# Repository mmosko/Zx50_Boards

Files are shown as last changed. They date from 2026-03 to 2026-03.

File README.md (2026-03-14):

# Zx50 Project Architecture Context

## Overview

The Zx50 is a custom 8-slot, passive backplane Z80 computer. It uses a "Shadow Bus" architecture where a Raspberry Pi Pico can take over the bus via DMA (~BUSRQ / ~BUSAK) to load RAM, debug, and monitor the system.

## Core Rules & Hardware

* Backplane: 8 slots. Fully terminated with 10K SIP pull-up resistors on Address, Data, and Control lines. Includes an ~IEI/~IEO interrupt daisy chain and heavy bulk capacitance (1000µF).

* CPU: Z80 running at 8 to 10 MHz.

* Clock System: A dedicated Clock Mezzanine board that generates a 40 MHz Master Clock (MCLK) for the Pi Picos, and uses a 74HC393 to divide it down to a 10 MHz ZCLK for the Z80. It uses an async-request latch system (1G79, 1G08, 1G32) to perfectly sync the CPU clock stopping/stepping with the Pi Pico's requests, ensuring no runt pulses.

* Logic Families: * 74AHCT (specifically 74AHCT244 and 74AHCT245) are used for bus transceivers to provide the strong ±8mA current needed to drive the backplane.

* Standard 74HC / 74AHC logic is used for local onboard glue logic.

* System Reset: Handled by an MCP1316M-46LE/OT Open-Drain Supervisor IC on the CPU card. It provides a ~200ms reset timeout to allow the backplane capacitors to charge and the Pi Pico bootloaders to initialize before the Z80 wakes up.

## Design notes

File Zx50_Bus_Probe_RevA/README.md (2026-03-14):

# Zx50 Bus Probe & Injector Card (Rev A)

## 1. Overview and Purpose
The Zx50 Bus Probe is a hybrid diagnostic tool designed specifically for a Z80-based Zx50 backplane architecture. It serves as an active oscilloscope probe, an arbitrary signal injector, and a digital logic analyzer tap. 

Instead of manually moving oscilloscope probes across an active backplane, the Zx50 Probe allows a user to digitally route any of the 72 backplane signals to a central BNC output, inject external signals via a BNC input, and monitor system health via an onboard UI.

There is a Receiver card that attaches to the Zx50 bus.  It has a Pi PICO as the interface to a host computer.  The Pico orchestrates the backplane signal multiplexing.  It is attached via SPI to an 18F4620 PIC that has two GPIO expanders.  The PIC is the Zx50 bus debugger.  It can read or write to the bus and it can control the clocks.  The 18F4620 uses its onboard SPI to talk to the GPIO expanders and the UART to talk to the Pico.  A to-be-determined serial protocol allows the Pico to send commands or read data from the 4620.  The intent is the 4620 has a simple command monitor and rarely needs flash updates.  The Pico has complex software in Python that is easier to program and update.

There is a Sender card that attaches to the Receiver via 2x5 ribbon cable.  The Sender card attaches to an AFG to put signals on backplane traces.  These can be monitored by the Receiver.  Both sender and receiver have high-speed op amps and BNC connectors to attach to lab equipment.

## 2. The Universal Board Architecture
To minimize fabrication costs and guarantee matched signal paths, the system is designed as a **Universal PCB**. A single board design can be populated differently to serve as either the "Receiver" (The Brain) or the "Sender" (The Drone).

* **The Receiver (Master):** Populated with a Raspberry Pi Pico (RP2040) and a PIC18F4620. It orchestrates the signal routing, generates hardware-level system clocks, handles high-speed Z80 interrupts (`~WAIT~`, `~INT~`), and hosts the physical User Interface.
* **The Sender (Slave):** The Pi Pico and PIC are left unpopulated. It relies on the Receiver to command its local analog matrix via a 10-pin right-angle IDC ribbon cable.
* **The Jumper Matrix (3x7 Block):** A physical 21-pin routing block determines the board's role by directing the 5V control signals:
  * **Position 1-2 (Receiver Mode):** The onboard Pico drives both the local analog matrix and the remote Sender board via the ribbon cable.
  * **Position 2-3 (Sender Mode / Mirror Mode):** The local analog matrix is driven by external signals arriving from the ribbon cable.

## 3. Core Subsystems

### A. The "Voltage Firewall" (Level Shifting)
The Pi Pico operates strictly at 3.3V, while the Zx50 backplane and logic operate at 5.0V. 
* A **`74AHCT541`** buffer acts as a unidirectional level shifter and line driver.
* The "T" (TTL-compatible) inputs interpret the Pico's 3.3V signals as a valid logic HIGH, stepping them up to a robust 5.0V to drive the local multiplexers and safely push signals down the ribbon cable to the Sender board.

### B. The Analog Matrix
The core of the probing capability is a massive 72-channel crosspoint matrix.
* **Multiplexers:** Nine `CD74HC4051E` 8-channel analog multiplexers (High-Speed CMOS variant chosen over legacy `CD4051BE` to ensure <70Ω $R_{ON}$ and >100MHz bandwidth for sharp Z80 square waves).
* **Decoding:** A 4-to-16 line decoder (`74HC154` or cascaded `74HC138`s) manages the Chip Select lines for the multiplexers. Sending address `1111` (15) targets a "Phantom Mux," safely disabling the entire matrix to isolate the test equipment from the bus.
* **Op-Amps:** High-speed `OPA356xxD` CMOS operational amplifiers buffer the analog signals immediately before the `IN` and `OUT` BNC jacks to prevent the oscilloscope or function generator from loading the backplane.

### C. The Dedicated Logic Analyzer Field
To support professional diagnostic equipment (e.g., Tektronix logic analyzers), the rear of the card features a raw, unbuffered test point field.
* Arranged in standard 2xN 2.54mm pitch groupings spaced out by function: `ADDR [0:15]`, `DATA [0:7]`, `CTRL [0:7]`, `SHADOW_DATA [0:7]`, `SHADOW_CTRL [0:7]`, and `CLOCK [0:1]`.
* **Dedicated Ground Row:** Every signal pin is paired directly with an adjacent `GND` pin (Row 2), ensuring short return paths and pristine signal integrity for flying-lead probes.
* The headers are intentionally unbuffered, relying on the <2pF capacitance of professional logic analyzer pods to spy on the true analog state of the bus.

## 4. Mechanical & Physical Design

* **Asymmetric "Tower" Form Factor:** The PCB utilizes an inverted-T (or L-shaped) `Edge.Cuts` profile. The base fits the standard 5-inch Zx50 card dimensions, while the front UI section extends upward to 7 inches. This ensures the display and status LEDs clear the adjacent memory/CPU cards in the chassis.
* **User Interface:**
  * **Primary Display:** An `EA DIP205-4` 20x4 Character LCD, mounted flush to the PCB. It runs natively on the Pico's 3.3V SPI bus, with a dedicated 33Ω resistor dropping the 5V rail for the yellow/green backlight.
  * **Status LEDs:** Three right-angle horizontal LEDs (`CLK`, `MCLK`, `PWR`) mounted on the top edge of the board to provide immediate, bench-visible heartbeat and clock status.
* **Horizontal Interconnects:** The PIC ICSP programming header (`J4`) and the Sender/Receiver ribbon cable header (`J8`) use right-angle footprints to prevent cable collisions with adjacent Zx50 cards.

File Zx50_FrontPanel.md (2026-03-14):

# Zx50 Front Panel Card

This card drives the flashy front panel.  The front panel will have LEDs for bus state
plus a programmable LCD display (e.g. EA DIP205G-4NLED SPI).  It will also have
some system control switches.

## Physical Interface

- LCD Display: Driven by a Pi PICO on the front panel card, it can display messages
from the Pico or the Z80.

- LEDs
  - Z80 Address [0:15]
  - Z80 Data [0:8]
  - Z80 Control (about 12 of them)
  - Shadow Bus data [0:8]
  - Shadow Bus control (8 lines)
  - Power
  - Some of these could be hex digit mult-segment

- Switches
  - Power switch (e.g. SPST to turn on power supply)
  - Run/Stop (SPST pulls line low)
  - Step (momentary, pulls line low)

## Pico Interface

The Pico controls multple tri-state buffers (e.g. '244) attached to the different
8-bit buses (address hi, address low, data, control, shadow data, shadow control).
It reads each bus periodically and updates the front panel LEDs.

There is an IORQ decoder chip that fires an interrupt whenever the Z80 writes to
the front panel card's IO address.  The Z80 can transfer commands to the Pico
by using, e.g. OTIR transfers.  During an I/O instruction, the Z80 places the contents of the B register on the upper address bus (A8-A15), while the C register (the port address) goes on the lower bus (A0-A7).

Because OTIR decrements B with every loop, the Pico literally gets a real-time hardware countdown timer handed to it on A8-A15 with every single byte.  At the end of the burst,
the Pico can udpate the LCD display from its local memory.

Because the Pico has fast PIO (Programmable I/O) state machines, it does not even need to write this in C. You can write a tiny 4-line PIO assembly program that just sits there, watching the ~IORQ pin, and instantly pushes those 16 pins into a DMA FIFO buffer for your main Pico code to read at its leisure. It won't miss a single byte, even at 8MHz, 10MHz, or 20MHz.

## Shadow Bus transfers

The other option is for the Pico to work as a Shadow Bus slave or master.  The Z80 can setup a
DMA transfer from meory to the Pico, and this can then run at 40 MHz.

See [Zx50 Bus Protocol](https://github.com/mmosko/Zx50Bus/blob/main/README.md).

## Physical UI and the Zx50 CPU Card

The Front Panel card attaches via two 2x50 cables to the front panel.  One is for the
SPI control of the LCD display.  The other is for updating the LCDs and the physical
switches.  A small MCU (e.g. small 18Fxxxx) controls the LEDs based on commands from
the Pico.

This arrangement allows one to use the fancy front panel control card or bypass it
directly to the CPU card for a minimum interface.

Front Panel Connector (exact pinout TBD, 2x5 IDC)
1. +5V
2. +5V
3. TX (from Pico level shifter)
4. RX (to Pico level shifter)
5. TBD
6. Power switch
7. Reset switch
8. Step switch
9. GND
10. GND

Note that the Zx50 CPU card has the exact same header on it, so one could attach

LCD Display Connector (2x5 IDC)
- 3.3V
- SCLK
- SDI (to Pico)
- SDO (from pico)
- GND
- RST (~MCLR)

## Interface to Zx50 Bus Probe

It is desirable for the Zx50 Bus Probe to see the Step switch.  The Reset switch is
already on the bus.  The Step switch will use Pin 80 (labelled AUX).  Both the
Zx80 CPU card and the Front Panel card will tie the Front Panel connector 
Step switch (after debouncing) to pin 80.  The Zx50 bus already has a pull up on AUX, so
the switches only need to pull low.

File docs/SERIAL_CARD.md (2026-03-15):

# Zx50 Serial I/O & Timer Card (CTC + DART)

## 1. Overview
This card provides the Zx50 system with its primary human-machine interface (via two serial ports) and precision hardware timing. It combines a **Z80 DART** (Dual Asynchronous Receiver/Transmitter) for serial communications and a **Z80 CTC** (Counter/Timer Circuit) for programmable baud rate generation and system tick interrupts.

## 2. Core Chip Manifest
1. **Z80 DART (Z84C40):** The dual serial controller.
2. **Z80 CTC (Z84C30):** The 4-channel timer (provides baud rate clocks to the DART and system ticks).
3. **74AHCT245:** Octal bus transceiver (Firewall for the `D0-D7` data bus).
4. **74AHCT138:** 3-to-8 line decoder (Address slicing for the Z80 I/O space).
5. **MAX232 (or MAX3232):** RS-232 level shifter charge-pump (Dedicated to Serial Port 1).
6. **7.3728 MHz Oscillator:** A standard 4-pin active crystal oscillator can (feeds the CTC's clock inputs).
7. **FTDI DB9-USB-D5:** Standalone USB-to-TTL module (Physical connector and level translator for Serial Port 0).
8. *(Optional Glue Logic):* `74AHCT32` or `74AHCT04` to qualify `~IORQ` and `~M1` for the address decoder.

## 3. The Output Stages (The Split Design)
* **Serial 0 (USB via FTDI):**
  * **Source:** Z80 DART Channel A.
  * **Connector:** FTDI DB9-USB-D5 module.
  * **Voltages:** 5V TTL logic. The DART's `TXA`, `RXA`, `~RTSA~`, and `~CTSA~` pins connect *directly* to the module's footprint.
* **Serial 1 (Classic RS-232):**
  * **Source:** Z80 DART Channel B.
  * **Connector:** Standard Right-Angle DB9 Female (PCB Mount).
  * **Voltages:** True RS-232 (±10V). The DART's `TXB`, `RXB`, `~RTSB~`, and `~CTSB~` pins route through the `MAX232` level-shifting IC before hitting the DB9.

## 4. Hardware Activity LEDs
To provide immediate visual feedback during data transmission, the board features hardware-driven activity LEDs:
* **Implementation:** High-efficiency LEDs are connected directly to the `TXA` and `TXB` output pins of the DART, pulled to ground through a 1KΩ or 2.2KΩ current-limiting resistor.
* **Result:** The LEDs will naturally flicker exactly when bytes are being shifted out of the UART, requiring zero software overhead or modem control line initialization.

## 5. The Baud Rate Engine (The CTC Hack)
Instead of using a dedicated baud rate generator chip, this board uses the classic Zilog design pattern: **Using the CTC to drive the DART.**
* **The Clock:** The `7.3728 MHz` crystal oscillator feeds the CTC's clock inputs (`CLK/TRG0` and `CLK/TRG1`). This specific frequency divides down perfectly into standard baud rates (115200, 9600, etc.).
* **The Routing:** * CTC Channel 0 Output (`ZC/TO0`) $\rightarrow$ DART Channel A `RxCA` / `TxCA` pins.
  * CTC Channel 1 Output (`ZC/TO1`) $\rightarrow$ DART Channel B `RxCB` / `TxCB` pins.
* **Result:** The Z80 can dynamically change the baud rate of either serial port on the fly by writing a new divisor to the respective CTC channel.

## 6. Interrupt Priority & The Daisy Chain
Both the CTC and the DART utilize **Z80 Mode 2 Vectored Interrupts**. Because they sit on the same physical card, their interrupt priority is hardwired using the Zx50 Backplane's `IEI` and `IEO` lines.
* **Routing Path:** `Backplane IEI` $\rightarrow$ `CTC IEI` | `CTC IEO` $\rightarrow$ `DART IEI` | `DART IEO` $\rightarrow$ `Backplane IEO`.
* **Priority:** The CTC has a higher interrupt priority than the DART. 

## 7. Addressing Configuration
Both chips map exclusively to the Z80 **I/O Space**.
* **DART:** Requires 4 contiguous ports (driven by `C/~D` and `B/~A` pins).
* **CTC:** Requires 4 contiguous ports (driven by `CS0` and `CS1` pins).
* **Decoder (74AHCT138):** Slices the lower 8 bits of the address bus. Assuming a base address of `0x80`:
  * `0x80 - 0x83`: Mapped to the CTC `~CE`.
  * `0x84 - 0x87`: Mapped to the DART `~CE`.

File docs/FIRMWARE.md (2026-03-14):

# Zx50 Bus Probe: Firmware Development Plan

## Phase 1: PIC18F4620 "Ghost Mode"
**Goal:** Guarantee the PIC processor boots up completely transparent to the Zx50 backplane to prevent electrical contention.
* **Toolchain:** Microchip MPLAB X & XC8 Compiler.
* **Process:** 1. Write a minimal `main.c` that initializes the system clock.
  2. Write `0xFF` to `TRISA`, `TRISB`, `TRISC`, `TRISD`, and `TRISE`. This explicitly sets every single GPIO pin to a High-Impedance (Input) state.
  3. Disable analog multiplexing on digital pins (`ADCON1 = 0x0F` or equivalent for the 4620).
  4. Enter a `while(1) { Sleep(); }` loop. 
* **Outcome:** The PIC is effectively removed from the circuit, safely clearing the runway for the Pi Pico.

## Phase 2: Automated Backplane Characterization
**Goal:** Use the Pi Pico to inject high-speed signals into the naked backplane while a PC orchestrates measurements via the Tektronix MDO3034.
* **Toolchain:** C/C++ SDK (Pico), Python + `pyvisa` (PC).
* **Process:**
  1. **Pico Firmware:** Write a simple USB-Serial command parser that listens for commands like `FREQ 10000000`. Use the Pico's PIO (Programmable I/O) to generate a mathematically perfect square wave on a designated Shadow Bus pin at the requested frequency.
  2. **Python Orchestrator:** Write a script on the PC that:
     * Connects to the Pico (COM port) and the Tektronix (Ethernet/IP).
     * Commands the Pico to start generating a 1MHz clock.
     * Commands the Tektronix to Auto-Scale, measure Peak-to-Peak voltage on the active line, and measure crosstalk (Vpp) on an adjacent quiet line.
     * Steps the frequency up to 40MHz in 1MHz increments, logging the data to a CSV.
* **Outcome:** A comprehensive bandwidth and crosstalk profile of the physical OSH Park backplane.

## Phase 3: Inter-Processor Communication (IPC)
**Goal:** Establish a reliable command-and-control protocol between the PIC and the Pico.
* **Architecture:** The Pico acts as the "High-Speed Brawn" (DMA, 40MHz signaling), while the PIC acts as the "Supervisor Brain" (handling the analog muxes `U2`-`U12` and steady-state Z80 monitoring).
* **Physical Layer:** Utilize the dedicated UART (`TX`/`RX`) or SPI pins running between the two chips on the Bus Probe board. 
* **Protocol:** Implement a simple packetized serial protocol (e.g., `[SYNC] [LENGTH] [COMMAND] [PAYLOAD] [CHECKSUM]`). 
  * Example Command: Pico tells PIC, *"Set Mux Array to route Z80 Address Line A15 to Analog Channel 1."*

## Phase 4: Full Bus Master & Monitor
**Goal:** Develop the software to freeze the Z80, take over the bus, and inject/read data.
* **Process:** 1. Pico asserts `~BUSRQ` and waits for `~BUSAK` from the Z80.
  2. Pico asserts `~OE` on the Bus Probe's transceiver firewall to physically connect itself to the backplane.
  3. Pico executes DMA transfers to memory or I/O, utilizing the PIC to monitor analog signal integrity during the transfer.

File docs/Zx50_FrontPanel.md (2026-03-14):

# Zx50 Front Panel Card

This card drives the flashy front panel.  The front panel will have LEDs for bus state
plus a programmable LCD display (e.g. EA DIP205G-4NLED SPI).  It will also have
some system control switches.

## Physical Interface

- LCD Display: Driven by a Pi PICO on the front panel card, it can display messages
from the Pico or the Z80.

- LEDs
  - Z80 Address [0:15]
  - Z80 Data [0:8]
  - Z80 Control (about 12 of them)
  - Shadow Bus data [0:8]
  - Shadow Bus control (8 lines)
  - Power
  - Some of these could be hex digit mult-segment

- Switches
  - Power switch (e.g. SPST to turn on power supply)
  - Run/Stop (SPST pulls line low)
  - Step (momentary, pulls line low)

## Pico Interface

The Pico controls multple tri-state buffers (e.g. '244) attached to the different
8-bit buses (address hi, address low, data, control, shadow data, shadow control).
It reads each bus periodically and updates the front panel LEDs.

There is an IORQ decoder chip that fires an interrupt whenever the Z80 writes to
the front panel card's IO address.  The Z80 can transfer commands to the Pico
by using, e.g. OTIR transfers.  During an I/O instruction, the Z80 places the contents of the B register on the upper address bus (A8-A15), while the C register (the port address) goes on the lower bus (A0-A7).

Because OTIR decrements B with every loop, the Pico literally gets a real-time hardware countdown timer handed to it on A8-A15 with every single byte.  At the end of the burst,
the Pico can udpate the LCD display from its local memory.

Because the Pico has fast PIO (Programmable I/O) state machines, it does not even need to write this in C. You can write a tiny 4-line PIO assembly program that just sits there, watching the ~IORQ pin, and instantly pushes those 16 pins into a DMA FIFO buffer for your main Pico code to read at its leisure. It won't miss a single byte, even at 8MHz, 10MHz, or 20MHz.

## Shadow Bus transfers

The other option is for the Pico to work as a Shadow Bus slave or master.  The Z80 can setup a
DMA transfer from meory to the Pico, and this can then run at 40 MHz.

See [Zx50 Bus Protocol](https://github.com/mmosko/Zx50Bus/blob/main/README.md).

## Physical UI and the Zx50 CPU Card

The Front Panel card attaches via two 2x50 cables to the front panel.  One is for the
SPI control of the LCD display.  The other is for updating the LCDs and the physical
switches.  A small MCU (e.g. small 18Fxxxx) controls the LEDs based on commands from
the Pico.

This arrangement allows one to use the fancy front panel control card or bypass it
directly to the CPU card for a minimum interface.

Front Panel Connector (exact pinout TBD, 2x5 IDC)
1. +5V
2. +5V
3. TX (from Pico level shifter)
4. RX (to Pico level shifter)
5. Power switch
6. Run switch
7. Reset switch
8. Step_N switch
9. GND
10. GND

Note that the Zx50 CPU card has the exact same header on it, so one could attach

LCD Display Connector (2x5 IDC)
- 3.3V
- SCLK
- SDI (to Pico)
- SDO (from pico)
- GND
- RST (~MCLR)

Wiring
- If only the CPU card is installed, the front panel Connetor is wired directly to
the CPU card.
- If the Front Panel Card is installed, the front panel connector goes to the Front panel
card, and then a daisy chain short ribbon cables goes from the front pane card to the cpu card,
to wire the RUN and STEP switches to the clock mezzanine. The CPU card does not use the AUX pin.
- There will be some 2 position jumpers on the CPU card to connect pin 79 to RUN and pin 80
to STEP_N, in case I want to do that.  Otherwise, it will leave the 16-bit GPIO pins free.

## Interface to Zx50 Bus Probe

It is desirable for the Zx50 Bus Probe to see the Step switch.  The Reset switch is
already on the bus.  The Step switch will use Pin 80 (labelled AUX). 

It is assumed that if one is using the bus probe to control the system, there is a control
PC somewhere with the main interface and the STEP switch is just a convencience.

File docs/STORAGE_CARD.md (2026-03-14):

# Zx50 NetStorage Card (Combo Ethernet & USB/SD)

## 1. Overview
The Zx50 NetStorage card provides the system with physical network connectivity and FAT16/FAT32 mass storage. By utilizing dual 8-bit parallel interfaces, both subsystems can achieve high-speed data transfers (and native Pi Pico DMA compatibility over the Shadow Bus) without bottlenecking the Z80.

## 2. Core Components
* **Ethernet:** **WIZnet W5300**. A high-performance hardware TCP/IP stack with a native 8-bit/16-bit parallel bus. (Configured in 8-bit mode). It features 8 independent hardware sockets and 128KB of internal TX/RX buffer memory.
* **Mass Storage:** **WCH CH376S**. A file management control chip that natively handles FAT file systems on USB flash drives and SD cards via an 8-bit parallel interface.
* **Bus Firewall:** Two `74AHCT245` transceivers for the Data bus, strictly controlled by the board's address decoder to prevent bus contention.

## 3. Addressing Strategy: Memory vs. I/O
The Z80 has two distinct addressing spaces: a 64KB Memory space and a 256-port (typically) I/O space. 

### Mass Storage (CH376S) -> I/O Mapped
* **Requirement:** The CH376S only requires **two** addresses: a Data port and a Command port.
* **Implementation:** We will map this to the standard Z80 I/O space using a `74AHCT138` decoder. For example, mapping it to I/O Ports `0x40` (Data) and `0x41` (Command). This uses almost zero real estate in the I/O map and is perfect for standard `IN A, (n)` and `OUT (n), A` instructions.

### Ethernet (W5300) -> Memory Mapped
* **Requirement:** The W5300 has a massive register set requiring **10 address lines** (`A0` through `A9`), effectively taking up 1024 bytes of address space. 
* **Implementation:** While the Z80 *can* do 16-bit I/O addressing via `IN A, (C)`, trying to cram 1KB of registers into the I/O space is messy. Instead, we will **Memory Map** the W5300. We will dedicate a 2KB or 4KB "window" in the Z80's upper memory space (e.g., `0xE000` to `0xE3FF`). 
* **Advantage:** Memory mapping allows the Z80 to use high-speed block move instructions (`LDIR`, `LDDR`) to blast data into the Ethernet transmit buffers exponentially faster than iterating through I/O ports.

## 4. Interrupts
Both chips feature active-low hardware interrupt pins (`~INT`). These will be tied into the Zx50 Backplane's open-drain `~INT` line, allowing either the Ethernet chip (e.g., "Packet Received") or the Storage chip (e.g., "File Read Complete") to flag the Z80 asynchronously.

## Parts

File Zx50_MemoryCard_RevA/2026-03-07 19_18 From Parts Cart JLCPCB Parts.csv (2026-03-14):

Parts Type | JLCPCB Part # | MFR Part # | Description | Unit Price | Qty | Total Price
stock | C14663 | CC0603KRX7R9BB104 | 100nF 50V X7R ±10% 0603 Multilayer Ceramic Capacitors MLCC - SMD/SMT ROHS | 0.0026 | 24 | 0.07
stock | C2062861 | IS61C256AL-12JLI-TR | -40℃~+85℃ 12ns 256Kbit 4.5V~5.5V 40mA 450uA Parallel Port (Parallel) SOJ-28 SRAM ROHS | 1.7867 | 1 | 1.79
stock | C3018881 | CY7C1049DV33-10ZSXIT | -40℃~+85℃ 10mA 10ns 3V~3.6V 4Mbit 90mA TSOPII-44-10.2mm SRAM ROHS | 9.0217 | 2 | 18.05
stock | C131956 | SN74ABT541BPWR | -40℃~+85℃ 1 250uA 2ns@5V,50pF 32mA 4.5V~5.5V 64mA 74ABT 8 Tri-State TSSOP-20 Buffers, Drivers, Receivers, Transceivers ROHS | 1.0957 | 2 | 2.2
stock | C1548132 | SN74ABT245BDW | -40℃~+85℃ 250uA 2ns@5V,50pF 32mA 4.5V~5.5V 64mA 74ABT Bidirectional Tri-State SOIC-20-300mil Buffers, Drivers, Receivers, Transceivers ROHS | 0.8491 | 3 | 2.55
stock | C2676105 | SN74ABT16244ADGGR | -40℃~+85℃ 32mA 3mA 4 4 4.5V~5.5V 64mA 74ABT Tri-State TSSOP-48-6.1mm Buffers, Drivers, Receivers, Transceivers ROHS | 1.3661 | 1 | 1.37
stock | C31179 | ATF1508AS-10AU100 | TQFP-100(14x14) Programmable Logic Device (CPLDs/FPGAs) ROHS | 20.8308 | 1 | 20.84

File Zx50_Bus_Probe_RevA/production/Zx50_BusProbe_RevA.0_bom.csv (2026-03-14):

Designator | Footprint | Quantity | Value | LCSC Part #
A1 | RaspberryPi_Pico_Common_Unspecified | 1 | RaspberryPi_Pico
C1, C10, C11, C12, C13, C14, C15, C16, C17, C18, C19, C2, C20, C3, C4, C5, C6, C7, C8, C9 | C_Disc_D5.0mm_W2.5mm_P2.50mm | 20 | .1uF
C21 | CP_Radial_Tantal_D5.0mm_P2.50mm | 1 | 10uF
D1 | LED_D5.0mm_Horizontal_O1.27mm_Z3.0mm | 1 | MCLK
D2 | LED_D5.0mm_Horizontal_O1.27mm_Z3.0mm | 1 | CLK
D3 | LED_D5.0mm_Horizontal_O1.27mm_Z3.0mm | 1 | PWR
J1 | PinSocket_2x40_P2.54mm_Horizontal_Edge | 1 | Zx50_EdgeConnector
J10 | PinHeader_1x03_P2.54mm_Vertical | 1 | CH1
J11 | PinHeader_1x03_P2.54mm_Vertical | 1 | CH2
J12 | PinHeader_1x03_P2.54mm_Vertical | 1 | CH3
J15 | PinHeader_2x16_P2.54mm_Vertical_Row_Letter_Last | 1 | Z80_Addr
J16 | PinHeader_2x08_P2.54mm_Vertical_Row_Letter_Last | 1 | Z80_Data
J17 | PinHeader_2x08_P2.54mm_Vertical_Row_Letter_Last | 1 | Z80_Ctrl
J18 | PinHeader_2x02_P2.54mm_Vertical_Row_Letter_Last | 1 | Clock
J19 | PinHeader_2x08_P2.54mm_Vertical_Row_Letter_Last | 1 | SH_Data
J2 | BNC_Amphenol_B6252HB-NPP3G-50_Horizontal | 1 | OUT
J20 | PinHeader_2x08_P2.54mm_Vertical_Row_Letter_Last | 1 | SH_Ctrl
J3 | BNC_Amphenol_B6252HB-NPP3G-50_Horizontal | 1 | IN
J4 | PinHeader_1x06_P2.54mm_Horizontal_EDGE | 1 | PIC PGM
J5 | PinHeader_1x03_P2.54mm_Vertical | 1 | P0
J6 | PinHeader_1x03_P2.54mm_Vertical | 1 | P1
J7 | PinHeader_1x03_P2.54mm_Vertical | 1 | P2
J8 | IDC-Header_2x05_P2.54mm_Horizontal_Edge | 1 | Send/Recv Card
J9 | PinHeader_1x03_P2.54mm_Vertical | 1 | CH0
LCD1 | EA_DIG205G-4NLED | 1 | EA 205G-4NLED
R1, R2 | R_Axial_DIN0207_L6.3mm_D2.5mm_P10.16mm_Horizontal | 2 | 49.9R 1W 1%
R10 | R_Axial_DIN0207_L6.3mm_D2.5mm_P5.08mm_Vertical | 1 | 33R
R3, R4 | R_Axial_DIN0207_L6.3mm_D2.5mm_P10.16mm_Horizontal | 2 | 10k
R5 | R_Axial_DIN0207_L6.3mm_D2.5mm_P10.16mm_Horizontal | 1 | 2.2k
R6 | R_Axial_DIN0207_L6.3mm_D2.5mm_P10.16mm_Horizontal | 1 | 3.3k
R7, R8 | R_Axial_DIN0207_L6.3mm_D2.5mm_P5.08mm_Vertical | 2 | 2.2K
R9 | R_Axial_DIN0207_L6.3mm_D2.5mm_P5.08mm_Vertical | 1 | 470
U1, U13 | DIP-28_W7.62mm_Socket | 2 | MCP23S17_SP
U10, U11, U12, U2, U3, U4, U5, U8, U9 | DIP-16_W7.62mm_Socket | 9 | CD74HC4051E
U14 | SOIC-24W_7.5x15.4mm_P1.27mm | 1 | CD74HC154M96
U15, U16 | SOIC-8_3.9x4.9mm_P1.27mm | 2 | OPA356xxD
U17 | DIP-40_W15.24mm_Socket | 1 | PIC18F4620-I_P
U18 | DIP-20_W7.62mm_Socket | 1 | 74AHCT541
U6, U7 | DIP-20_W7.62mm_Socket | 2 | SN74ABT245BN

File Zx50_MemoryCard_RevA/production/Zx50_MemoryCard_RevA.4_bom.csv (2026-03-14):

Designator | Footprint | Quantity | Value | LCSC Part #
C1, C2, C26, C27, C3, C4, C5, C6, C7, C8, C9 | 0603 | 11 | 0.1uF | C14663
C10, C11, C13, C14, C15, C16, C17, C18, C19, C20, C21, C22, C23, C24, C25 | 0603 | 15 | .1uF | C14663
C12 | CP_Radial_Tantal_D5.0mm_P2.50mm | 1 | 10uF
D1, D2 | LED_D3.0mm_Horizontal_O1.27mm_Z2.0mm | 2 | LED
D3 | 0805 | 1 | YLW | C2296
D4, D5 | 0805 | 2 | BLUE | C2293
J1 | PinSocket_2x40_P2.54mm_Horizontal_Edge | 1 | Zx50_EdgeConnector
J2 | IDC-Header_2x05_P2.54mm_Vertical | 1 | JTAG
R1, R2 | R_Axial_DIN0207_L6.3mm_D2.5mm_P7.62mm_Horizontal | 2 | 470
R3, R4, R5 | 0805 | 3 | 470 | C17710
RN1 | R_Array_SIP6 | 1 | 10K
SW1 | SW_DIP_SPSTx05_Slide_9.78x14.88mm_W7.62mm_P2.54mm | 1 | SW_DIP_x05
U1, U5 | TSSOP-20_4.4x6.5mm_P0.65mm | 2 | SN74ABT541BN | C131956
U10, U11 | SOJ-36_10.16x23.495mm_P1.27mm | 2 | CY7C1049GN | C2955765
U12 | DIP-32_W15.24mm_Socket | 1 | SST39SF040
U2 | SOT-23-5 | 1 | 74AHCT1G04 | C52140419
U3 | SSOP-48_7.5x15.9mm_P0.635mm | 1 | SN74ABT16244ADL | C2869608
U4, U6, U7 | SOIC-20W_7.5x12.8mm_P1.27mm | 3 | 74ABT245 | C1548132
U8 | TQFP-100_14x14mm_P0.5mm | 1 | ATF1508AS-10AU100 | C31179
U9 | SOJ-28_7.62x18.415mm_P1.27mm | 1 | IS61C256AL-12JLI | C2062861

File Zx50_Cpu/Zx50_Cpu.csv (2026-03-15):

Reference | Qty | DigiKey_PN | Value | DNP | Exclude from BOM | Exclude from Board | Footprint | Datasheet
D1 | 1 |  | PWR |  |  |  | LED_THT:LED_D5.0mm | ~
U6 | 1 | MCP1318MT-46LE/OTCT-ND | MCP1316MT-46LE/OT |  |  |  | SOT-23-5_MC_MCH | MCP1318MT-46LE/OT
U4 | 1 |  | Z84C00xxP |  |  |  | Package_DIP:DIP-40_W15.24mm | https://archive.org/details/zilog-z-8400
U2,U3,U5,U7 | 4 | 296-1476-5-ND | SN74AHCT245N |  |  |  | Package_DIP:DIP-20_W7.62mm_Socket
U1 | 1 | 296-1088-1-ND | 74AHC1G14 |  |  |  | Package_TO_SOT_SMD:SOT-23-5_HandSoldering
SW1 | 1 | SW402-ND | RESET |  |  |  | Button_Switch_THT:SW_PUSH_6mm_H7.3mm | ~
R2 | 1 |  | 10k |  |  |  | Resistor_THT:R_Axial_DIN0207_L6.3mm_D2.5mm_P5.08mm_Vertical | ~
R1 | 1 |  | 470 |  |  |  | Resistor_THT:R_Axial_DIN0207_L6.3mm_D2.5mm_P10.16mm_Horizontal | ~
J4 | 1 | 732-2098-ND | Front Panel |  |  |  | zx50_footprints:IDC-Header_2x05_P2.54mm_Horizontal_Edge | ~
J3 | 1 | 732-2098-ND | Clock Mezzanine |  |  |  | Connector_PinSocket_2.54mm:PinSocket_2x05_P2.54mm_Horizontal | ~
J2 | 1 | S1012E-02-ND | FrontPanelConnect |  |  |  | Connector_PinSocket_2.54mm:PinSocket_2x02_P2.54mm_Vertical | ~
J1 | 1 | A34273-40-ND | Zx50_EdgeConnector |  |  |  | Connector_PinSocket_2.54mm:PinSocket_2x40_P2.54mm_Vertical_Oval | ~
C9 | 1 | 399-1418-ND | 10uF |  |  |  | Capacitor_THT:CP_Radial_Tantal_D5.0mm_P2.50mm | ~
C1,C2,C3,C4,C5,C6,C7,C8 | 8 | BC1101CT-ND | 0.1uF |  |  |  | Capacitor_THT:C_Disc_D5.0mm_W2.5mm_P5.00mm | ~

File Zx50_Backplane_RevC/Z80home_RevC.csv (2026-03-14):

Reference | Qty | Value | DigiKey_PN | SKU | DNP | Exclude from BOM | Exclude from Board | Footprint | Datasheet
C2,C3,C4,C5,C6,C7,C8,C9 | 8 | 0.1uF |  |  |  | Excluded from BOM |  | Capacitor_THT:C_Disc_D5.0mm_W2.5mm_P5.00mm | ~
C10,C11 | 2 | 100pF | 399-4264-ND |  |  | Excluded from BOM |  | Capacitor_THT:C_Disc_D5.0mm_W2.5mm_P5.00mm | ~
D1 | 1 | LED |  |  |  |  |  | LED_THT:LED_D5.0mm | ~
H1,H2,H3,H4,H5,H6 | 6 | MountingHole | SJ5003-0-ND |  |  | Excluded from BOM | Excluded from board | MountingHole:MountingHole_3.2mm_M3 | ~
J10 | 1 | GPIO SEL | 732-5316-ND |  |  |  |  | Connector_PinHeader_2.54mm:PinHeader_1x03_P2.54mm_Vertical | ~
R1 | 1 | 10K |  |  |  | Excluded from BOM |  | Resistor_THT:R_Axial_DIN0207_L6.3mm_D2.5mm_P10.16mm_Horizontal | ~
R2,R3 | 2 | 100 |  |  |  | Excluded from BOM |  | Resistor_THT:R_Axial_DIN0207_L6.3mm_D2.5mm_P10.16mm_Horizontal | ~
R4 | 1 | 470 |  |  |  | Excluded from BOM |  | Resistor_THT:R_Axial_DIN0207_L6.3mm_D2.5mm_P10.16mm_Horizontal | ~
R7 | 1 | 10K |  |  |  | Excluded from BOM |  | Resistor_THT:R_Axial_DIN0207_L6.3mm_D2.5mm_P5.08mm_Vertical | ~
RN1,RN2,RN3,RN6,RN8,RN9 | 6 | 10K | 4609X-1-103LF-ND |  |  |  |  | Resistor_THT:R_Array_SIP9 | http://www.vishay.com/docs/31509/csc.pdf
RN4 | 1 | 4.7K | 4611X-1-472LF-ND |  |  |  |  | Resistor_THT:R_Array_SIP11 | http://www.vishay.com/docs/31509/csc.pdf
RN5 | 1 | 2.2K | 4607X-1-222LF-ND |  |  |  |  | Resistor_THT:R_Array_SIP7 | http://www.vishay.com/docs/31509/csc.pdf
RN7 | 1 | 10K | 4604X-1-103LF-ND |  |  |  |  | Resistor_THT:R_Array_SIP4 | http://www.vishay.com/docs/31509/csc.pdf
J11 | 1 | POWER | 277-1025-ND | 1757268 |  |  |  | TerminalBlock_Phoenix:TerminalBlock_Phoenix_MKDS-1,5-4-5.08_1x04_P5.08mm_Horizontal | ~
C1 | 1 | 1000uf | 493-10815-ND | Nichicon URS1C102MHD |  |  |  | Capacitor_THT:CP_Radial_D10.0mm_P5.00mm | ~
J1,J2,J3,J4,J5,J6,J7,J8 | 8 | Conn_02x40_Odd_Even | S7115-ND | Sullins PPTC402LFBN-RC |  |  |  | Connector_PinSocket_2.54mm:PinSocket_2x40_P2.54mm_Vertical_Oval | ~

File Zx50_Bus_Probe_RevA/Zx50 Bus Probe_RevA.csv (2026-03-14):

Reference | Qty | Value | DNP | Digi-Key_PN | Exclude from BOM | SKU | Exclude from Board | Footprint | Datasheet
A1 | 1 | RaspberryPi_Pico |  | SC1634 |  |  |  | Module:RaspberryPi_Pico_Common_Unspecified | https://datasheets.raspberrypi.com/pico/pico-datasheet.pdf
C1,C2,C3,C4,C5,C6,C7,C8,C9,C10,C11,C12,C13,C14,C15,C16,C17,C18,C19,C20 | 20 | .1uF |  |  |  |  | Excluded from board | Capacitor_THT:C_Disc_D5.0mm_W2.5mm_P2.50mm | ~
C21 | 1 | 10uF |  |  |  |  |  | Capacitor_THT:CP_Radial_Tantal_D5.0mm_P2.50mm | ~
D1 | 1 | MCLK |  | 732-5015-ND |  |  |  | LED_THT:LED_D5.0mm_Horizontal_O1.27mm_Z3.0mm | ~
D2 | 1 | CLK |  | 732-5018-ND |  |  |  | LED_THT:LED_D5.0mm_Horizontal_O1.27mm_Z3.0mm | ~
D3 | 1 | PWR |  | 732-5016-ND |  |  |  | LED_THT:LED_D5.0mm_Horizontal_O1.27mm_Z3.0mm | ~
J1 | 1 | Zx50_EdgeConnector |  | A34273-40-ND |  |  |  | zx50_footprints:PinHeader_2x40_P2.54mm_Horizontal_Edge | ~
J2 | 1 | OUT |  | ARF1060-ND |  |  |  | Connector_Coaxial:BNC_Amphenol_B6252HB-NPP3G-50_Horizontal | ~
J3 | 1 | IN |  | ARF1060-ND |  |  |  | Connector_Coaxial:BNC_Amphenol_B6252HB-NPP3G-50_Horizontal | ~
J4 | 1 | PIC PGM |  | 732-5339-ND |  |  |  | zx50_footprints:PinHeader_1x06_P2.54mm_Horizontal_EDGE | ~
J5 | 1 | P0 |  | 732-5316-ND |  |  |  | Connector_PinHeader_2.54mm:PinHeader_1x03_P2.54mm_Vertical | ~
J6 | 1 | P1 |  | 732-5316-ND |  |  |  | Connector_PinHeader_2.54mm:PinHeader_1x03_P2.54mm_Vertical | ~
J7 | 1 | P2 |  | 732-5316-ND |  |  |  | Connector_PinHeader_2.54mm:PinHeader_1x03_P2.54mm_Vertical | ~
J8 | 1 | Send/Recv Card |  | 732-2098-ND |  |  |  | zx50_footprints:IDC-Header_2x05_P2.54mm_Horizontal_Edge | ~
J9 | 1 | CH0 |  | 732-5316-ND |  |  |  | Connector_PinHeader_2.54mm:PinHeader_1x03_P2.54mm_Vertical | ~
J10 | 1 | CH1 |  | 732-5316-ND |  |  |  | Connector_PinHeader_2.54mm:PinHeader_1x03_P2.54mm_Vertical | ~
J11 | 1 | CH2 |  | 732-5316-ND |  |  |  | Connector_PinHeader_2.54mm:PinHeader_1x03_P2.54mm_Vertical | ~
J12 | 1 | CH3 |  | 732-5316-ND |  |  |  | Connector_PinHeader_2.54mm:PinHeader_1x03_P2.54mm_Vertical | ~
J13,J14 | 2 | DISPL SOCKET |  | S5751-09-ND |  | NPPN091BFCN-RC |  | Connector_PinSocket_2.00mm:PinSocket_1x09_P2.00mm_Vertical | ~
J15 | 1 | Z80_Addr |  | 732-5307-ND |  |  |  | zx50_footprints:PinHeader_2x16_P2.54mm_Vertical_Row_Letter_Last | ~
J16 | 1 | Z80_Data |  | 732-5299-ND |  |  |  | zx50_footprints:PinHeader_2x08_P2.54mm_Vertical_Row_Letter_Last | ~
J17 | 1 | Z80_Ctrl |  | 732-5299-ND |  |  |  | zx50_footprints:PinHeader_2x08_P2.54mm_Vertical_Row_Letter_Last | ~
J18 | 1 | Clock |  | 732-5294-ND |  |  |  | zx50_footprints:PinHeader_2x02_P2.54mm_Vertical_Row_Letter_Last | ~
J19 | 1 | SH_Data |  | 732-5299-ND |  |  |  | zx50_footprints:PinHeader_2x08_P2.54mm_Vertical_Row_Letter_Last | ~
J20 | 1 | SH_Ctrl |  | 732-5299-ND |  |  |  | zx50_footprints:PinHeader_2x08_P2.54mm_Vertical_Row_Letter_Last | ~
LCD1 | 1 | EA 205G-4NLED |  | 1481-EADIP205G-4NLED-ND |  |  |  | zx50_footprints:EA_DIG205G-4NLED | https://mm.digikey.com/Volume0/opasdata/d220001/medias/docus/6592/dip2054epreliminary.pdf
R1,R2 | 2 | 49.9R 1W 1% |  | 541-CPF149R900FKRE6CT-ND |  |  | Excluded from board | Resistor_THT:R_Axial_DIN0207_L6.3mm_D2.5mm_P10.16mm_Horizontal | ~
R3 | 1 | 10k |  |  |  |  | Excluded from board | Resistor_THT:R_Axial_DIN0207_L6.3mm_D2.5mm_P10.16mm_Horizontal | ~
R4 | 1 | 10K |  |  |  |  | Excluded from board | Resistor_THT:R_Axial_DIN0207_L6.3mm_D2.5mm_P10.16mm_Horizontal | ~
R5 | 1 | 2.2k |  |  |  |  | Excluded from board | Resistor_THT:R_Axial_DIN0207_L6.3mm_D2.5mm_P10.16mm_Horizontal | ~
R6 | 1 | 3.3k |  |  |  |  | Excluded from board | Resistor_THT:R_Axial_DIN0207_L6.3mm_D2.5mm_P10.16mm_Horizontal | ~
R7,R8 | 2 | 2.2K |  |  |  |  | Excluded from board | Resistor_THT:R_Axial_DIN0207_L6.3mm_D2.5mm_P5.08mm_Vertical | ~
R9 | 1 | 470 |  |  |  |  | Excluded from board | Resistor_THT:R_Axial_DIN0207_L6.3mm_D2.5mm_P5.08mm_Vertical | ~
R10 | 1 | 33R |  |  |  |  | Excluded from board | Resistor_THT:R_Axial_DIN0207_L6.3mm_D2.5mm_P5.08mm_Vertical | ~
U1,U13 | 2 | MCP23S17_SP |  | MCP23S17-E/SP-ND |  |  |  | Package_DIP:DIP-28_W7.62mm_Socket | http://ww1.microchip.com/downloads/en/DeviceDoc/20001952C.pdf
U2,U3,U4,U5,U8,U9,U10,U11,U12 | 9 | CD74HC4051E | DNP | 296-12810-5-ND |  |  |  | Package_DIP:DIP-16_W7.62mm_Socket | http://www.ti.com/lit/ds/symlink/cd74hc4051.pdf
U6,U7 | 2 | SN74ABT245BN |  | 296-3970-5-ND |  |  |  | Package_DIP:DIP-20_W7.62mm_Socket | https://www.ti.com/lit/gpn/sn74abt245b
U14 | 1 | CD74HC154M96 |  | 296-24352-1-ND |  |  |  | Package_SO:SOIC-24W_7.5x15.4mm_P1.27mm | http://www.ti.com/lit/gpn/sn74HC154
U15,U16 | 2 | OPA356xxD |  | 296-12407-5-ND |  |  |  | Package_SO:SOIC-8_3.9x4.9mm_P1.27mm | http://www.ti.com/lit/ds/symlink/opa356.pdf
U17 | 1 | PIC18F4620-I_P |  | PIC18F4620-I/P-ND |  |  |  | Package_DIP:DIP-40_W15.24mm_Socket
U18 | 1 | 74AHCT541 |  | 296-4755-5-ND |  |  |  | Package_DIP:DIP-20_W7.62mm_Socket | https://www.ti.com/lit/ds/symlink/sn74ahct541.pdf
U19,U20,U21,U22,U23,U24,U25 | 7 | Jumper |  | 732-2678-ND |  |  | Excluded from board

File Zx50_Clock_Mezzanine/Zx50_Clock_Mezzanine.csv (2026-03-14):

Reference | Qty | Value | DigiKey_PN | SKU | DNP | Exclude from BOM | Exclude from Board | Footprint | Datasheet
C1 | 1 | 0.1 uF | 311-1140-1-ND |  |  |  |  | Capacitor_SMD:C_0805_2012Metric_Pad1.18x1.45mm_HandSolder | ~
C2,C3,C4,C5,C6,C7,C8 | 7 | 0.1uF | 311-1140-1-ND |  |  |  |  | Capacitor_SMD:C_0805_2012Metric_Pad1.18x1.45mm_HandSolder | ~
J1 | 1 | CLK_INPUT | 732-5316-ND | 61300311121 |  |  |  | Connector_PinHeader_2.54mm:PinHeader_1x03_P2.54mm_Vertical | ~
J2 | 1 | Conn_02x05_Odd_Even | 2057-PH2RA-10-UA-ND | PH2RA-10-UA |  |  |  | Connector_PinHeader_2.54mm:PinHeader_2x05_P2.54mm_Vertical | ~
J3 | 1 | Conn_Coaxial | ARF1178-ND | 31-5640-1010 |  |  |  | Connector_Coaxial:BNC_Amphenol_B6252HB-NPP3G-50_Horizontal | ~
J4 | 1 | CLK_DIV | 732-5316-ND | 61300311121 |  |  |  | Connector_PinHeader_2.54mm:PinHeader_1x03_P2.54mm_Vertical | ~
R1,R2 | 2 | 10K | 311-10.0KCRCT-ND |  |  |  |  | Resistor_SMD:R_0805_2012Metric_Pad1.20x1.40mm_HandSolder | ~
U1 | 1 | 74HC14 | MC74HC14ADR2GOSCT-ND |  |  |  |  | Package_SO:SOIC-14_3.9x8.7mm_P1.27mm | http://www.ti.com/lit/gpn/sn74HC14
U3 | 1 | 74AHC1G08 | 296-1091-1-ND - Cut Tape | SN74AHC1G08DBVR |  |  |  | Package_TO_SOT_SMD:SOT-23-5_HandSoldering | http://www.ti.com/lit/sg/scyt129e/scyt129e.pdf
U4 | 1 | S74LVC1G79 | 296-9849-1-ND | SN74LVC1G79DBVR |  |  |  | Package_TO_SOT_SMD:SOT-23-5_HandSoldering | https://www.ti.com/lit/gpn/sn74lvc1g79
U5 | 1 | 74AHC1G32 | 296-1093-1-ND | SN74AHC1G32DBVR |  |  |  | Package_TO_SOT_SMD:SOT-23-5_HandSoldering | http://www.ti.com/lit/sg/scyt129e/scyt129e.pdf
U6 | 1 | 74HC393 | 296-8317-5-ND | SN74HC393D |  |  |  | Package_SO:SOIC-14_3.9x8.7mm_P1.27mm | MC74HC393ADR2G
U7 | 1 | 74AHC125 | 296-4530-1-ND | SN74AHC125DR |  |  |  | Package_SO:SOIC-14_3.9x8.7mm_P1.27mm
Y1 | 1 | SG-8002DC | 17-2485264-1-ND |  |  |  |  | Package_DIP:DIP-8_W7.62mm_Socket | https://support.epson.biz/td/api/doc_check.php?mode=dl&lang=en&Parts=SG-8002DC
U2 | 1 | 74HC74 | 296-1204-1-ND | SN74HC74DR |  |  |  | Package_SO:SOIC-14_3.9x8.7mm_P1.27mm | http://www.ti.com/general/docs/suppproductinfo.tsp?distId=10

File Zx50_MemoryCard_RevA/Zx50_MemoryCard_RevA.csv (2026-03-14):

Reference | Qty | DigiKey_PN | SKU | LCSC | Value | DNP | Exclude from BOM | Exclude from Board | Footprint | Datasheet
C12 | 1 |  |  |  | 10uF |  | Excluded from BOM |  | Capacitor_THT:CP_Radial_Tantal_D5.0mm_P2.50mm | ~
D1,D2 | 2 |  |  |  | LED |  | Excluded from BOM |  | LED_THT:LED_D3.0mm_Horizontal_O1.27mm_Z2.0mm | ~
J1 | 1 | 2057-PH2RA-80-UA-ND | PH2RA-80-UA |  | Zx50_EdgeConnector |  |  |  | zx50_footprints:PinSocket_2x40_P2.54mm_Horizontal_Edge | ~
J2 | 1 | 732-2094-ND | 61201021621 |  | JTAG |  |  |  | Connector_IDC:IDC-Header_2x05_P2.54mm_Vertical | ~
MISC1 | 1 | 123-AR32-HZL-TT-ND | R 32-HZL-TT |  | ~ |  | Excluded from BOM | Excluded from board | DIP-32 socket
R1,R2 | 2 |  |  |  | 470 |  | Excluded from BOM |  | Resistor_THT:R_Axial_DIN0207_L6.3mm_D2.5mm_P7.62mm_Horizontal | ~
U12 | 1 | SST39SF040-70-4C-PHE-ND | SST39SF040-70-4C-PHE |  | SST39SF040 |  |  |  | Package_DIP:DIP-32_W15.24mm_Socket | http://ww1.microchip.com/downloads/en/DeviceDoc/25022B.pdf
SW1 | 1 | CT2085-ND |  | 208-5 | SW_DIP_x05 |  |  |  | Button_Switch_THT:SW_DIP_SPSTx05_Slide_9.78x14.88mm_W7.62mm_P2.54mm | ~
RN1 | 1 | 4606X-AP1-103LFCT-ND |  | 4606X-AP1-103LF | 10K |  |  |  | Resistor_THT:R_Array_SIP6 | http://www.vishay.com/docs/31509/csc.pdf
D4,D5 | 2 |  |  | C2293 | BLUE |  | Excluded from BOM |  | LED_SMD:LED_0805_2012Metric | ~
D3 | 1 |  |  | C2296 | YLW |  | Excluded from BOM |  | LED_SMD:LED_0805_2012Metric | ~
C1,C2,C3,C4,C5,C6,C7,C8,C9,C26,C27 | 11 |  |  | C14663 | 0.1uF |  | Excluded from BOM |  | Capacitor_SMD:C_0603_1608Metric | ~
C10,C11,C13,C14,C15,C16,C17,C18,C19,C20,C21,C22,C23,C24,C25 | 15 |  |  | C14663 | .1uF |  | Excluded from BOM |  | Capacitor_SMD:C_0603_1608Metric | ~
R3,R4,R5 | 3 |  |  | C17710 | 470 |  | Excluded from BOM |  | Resistor_SMD:R_0805_2012Metric | ~
U8 | 1 |  |  | C31179 | ATF1508AS-10AU100 |  | Excluded from BOM |  | Package_QFP:TQFP-100_14x14mm_P0.5mm
U1,U5 | 2 |  |  | C131956 | SN74ABT541BN |  | Excluded from BOM |  | Package_SO:TSSOP-20_4.4x6.5mm_P0.65mm | https://www.ti.com/lit/gpn/sn74abt541b
U4,U6,U7 | 3 |  |  | C1548132 | 74ABT245 |  | Excluded from BOM |  | Package_SO:SOIC-20W_7.5x12.8mm_P1.27mm | https://www.ti.com/lit/gpn/sn74abt245b
U9 | 1 |  |  | C2062861 | IS61C256AL-12JLI |  | Excluded from BOM |  | Package_SO:SOJ-28_7.62x18.415mm_P1.27mm | http://www.issi.com/WW/pdf/61-64C256AL.pdf
U3 | 1 |  |  | C2869608 | SN74ABT16244ADL |  | Excluded from BOM |  | Package_SO:SSOP-48_7.5x15.9mm_P0.635mm | https://www.ti.com/lit/gpn/sn74abt16244a
U10,U11 | 2 |  |  | C2955765 | CY7C1049GN |  | Excluded from BOM |  | Package_SO:SOJ-36_10.16x23.495mm_P1.27mm
U2 | 1 |  |  | C52140419 | 74AHCT1G04 |  | Excluded from BOM |  | Package_TO_SOT_SMD:SOT-23-5 | http://www.ti.com/lit/sg/scyt129e/scyt129e.pdf

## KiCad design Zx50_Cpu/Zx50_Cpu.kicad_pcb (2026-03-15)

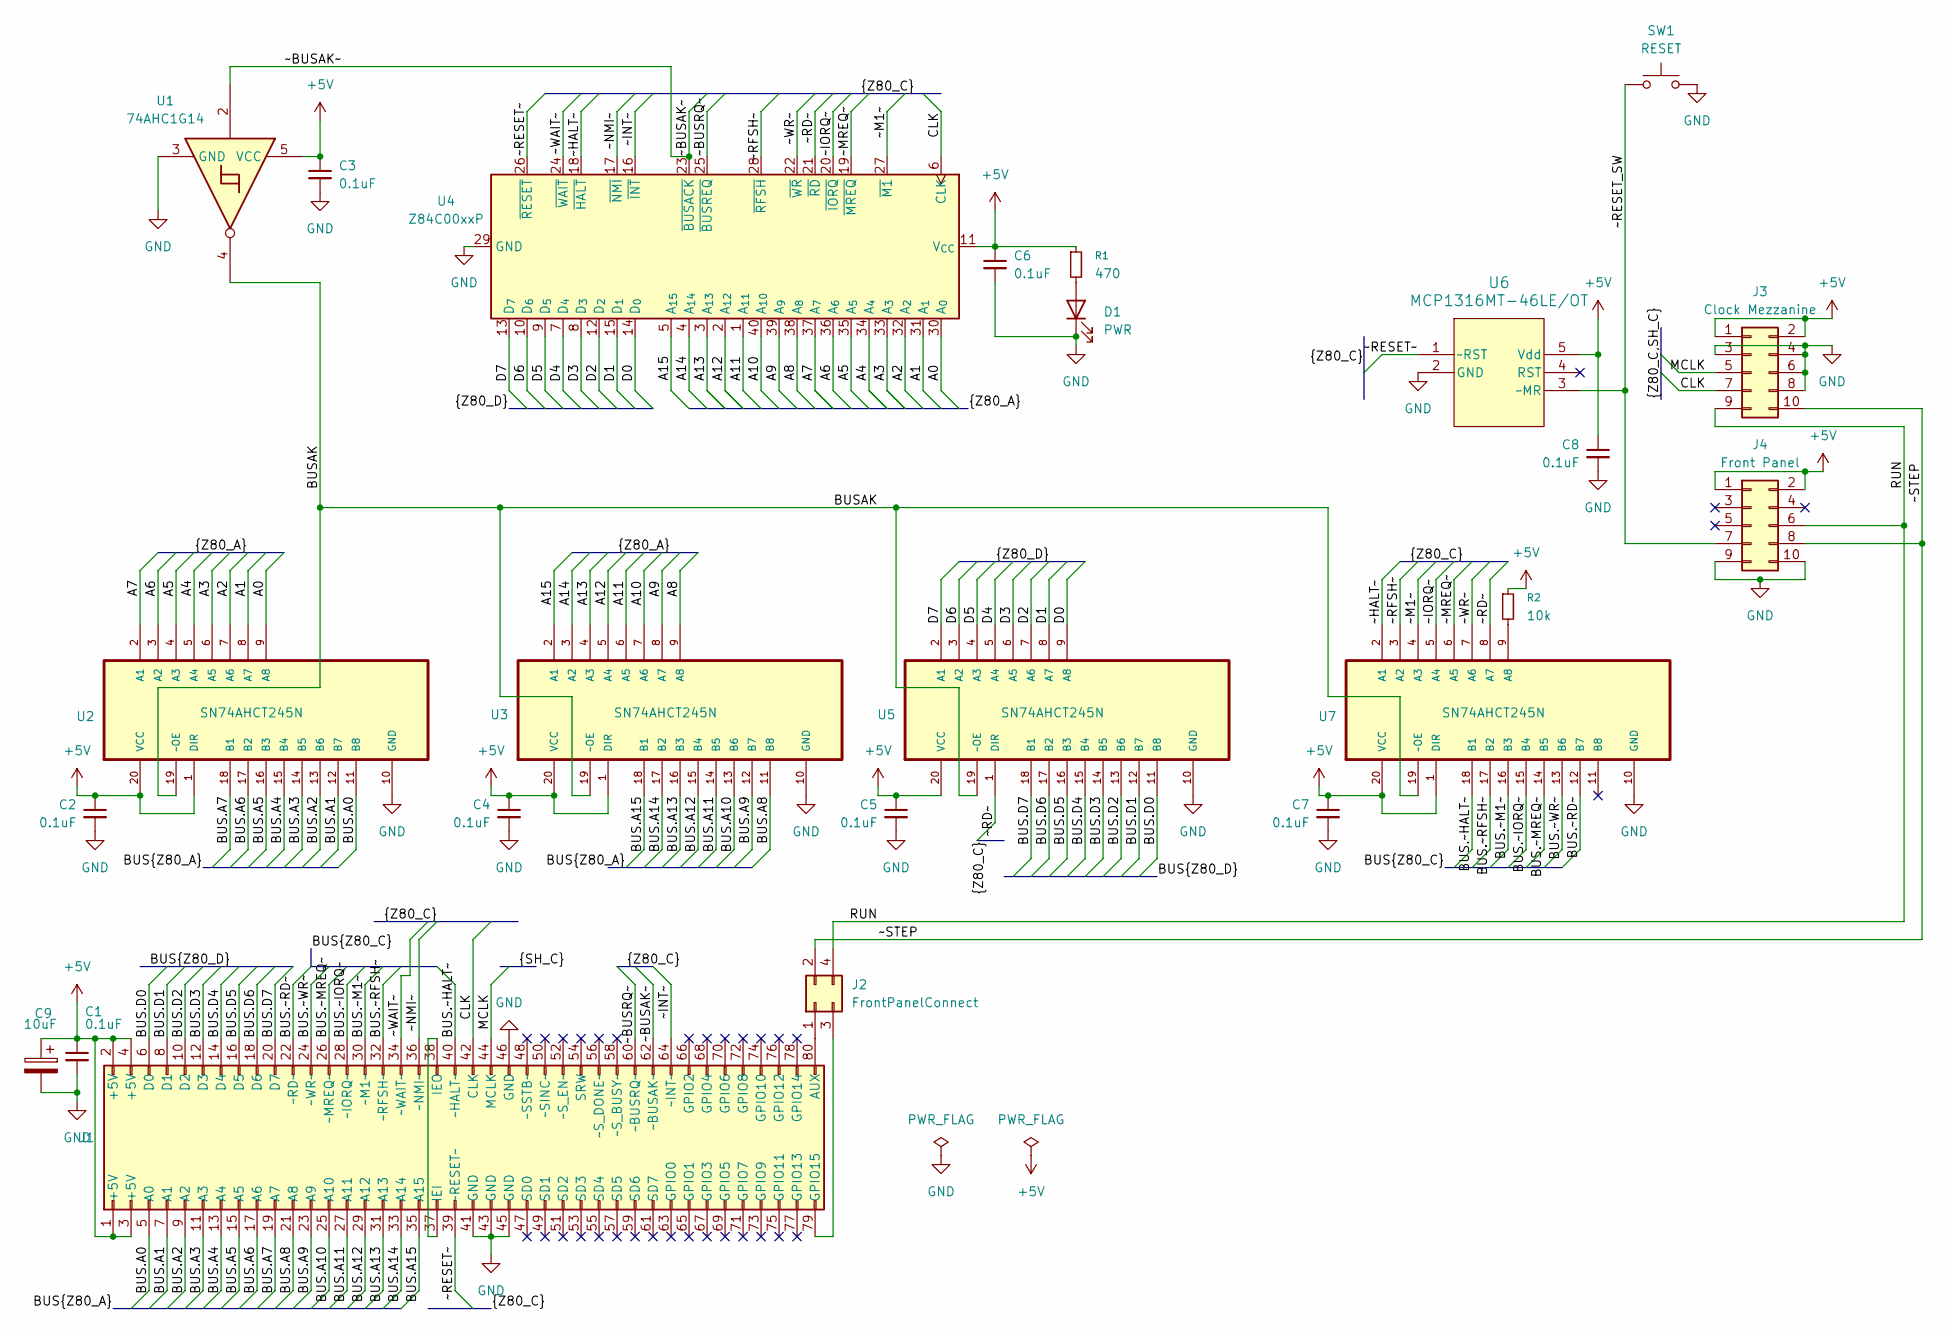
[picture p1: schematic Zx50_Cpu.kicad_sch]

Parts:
C1, C2, C3, C4, C5, C6, C7, C8: 0.1uF; C_Disc_D5.0mm_W2.5mm_P5.00mm; DigiKey_PN BC1101CT-ND
C9: 10uF; CP_Radial_Tantal_D5.0mm_P2.50mm; DigiKey_PN 399-1418-ND
D1: PWR; LED_D5.0mm
J1: Zx50_EdgeConnector; PinSocket_2x40_P2.54mm_Vertical_Oval; DigiKey_PN A34273-40-ND
J2: FrontPanelConnect; PinSocket_2x02_P2.54mm_Vertical; DigiKey_PN S1012E-02-ND
J3: Clock Mezzanine; PinSocket_2x05_P2.54mm_Horizontal; DigiKey_PN S5558-ND
J4: Front Panel; IDC-Header_2x05_P2.54mm_Horizontal_Edge; DigiKey_PN 732-2098-ND
R1: 470; R_Axial_DIN0207_L6.3mm_D2.5mm_P10.16mm_Horizontal
R2: 10k; R_Axial_DIN0207_L6.3mm_D2.5mm_P5.08mm_Vertical
SW1: RESET; SW_PUSH_6mm_H7.3mm; DigiKey_PN SW402-ND
U1: 74AHC1G14; SOT-23-5_HandSoldering; DigiKey_PN 296-1088-1-ND
U2, U3, U5: SN74AHCT245N; DIP-20_W7.62mm_Socket; MPN SN74AHCT245N; Digikey_PN 296-1476-5-ND
U4: Z84C00xxP; DIP-40_W15.24mm
U6: MCP1316MT-46LE/OT; SOT-23-5_MC_MCH; DigiKey_PN MCP1318MT-46LE/OTCT-ND
U7: SN74AHCT245N; DIP-20_W7.62mm_Socket; MPN SN74AHCT245N; DigiKey_PN 296-1476-5-ND

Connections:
+5V: C1.1, C2.1, C3.1, C4.1, C5.1, C6.1, C7.1, C8.1, C9.1, J1.1 (+5V), J1.2 (+5V), J1.3 (+5V), J1.4 (+5V), J3.1, J3.2, J4.1, J4.2, R1.1, R2.1, U1.5 (VCC), U2.1 (DIR), U2.20 (VCC), U3.1 (DIR), U3.20 (VCC), U4.11 (V_{CC}), U5.20 (VCC), U6.5 (Vdd), U7.1 (DIR), U7.20 (VCC)
/A0: U2.9 (A8), U4.30 (A_{0})
/A1: U2.8 (A7), U4.31 (A_{1})
/A2: U2.7 (A6), U4.32 (A_{2})
/A3: U2.6 (A5), U4.33 (A_{3})
/A4: U2.5 (A4), U4.34 (A_{4})
/A5: U2.4 (A3), U4.35 (A_{5})
/A6: U2.3 (A2), U4.36 (A_{6})
/A7: U2.2 (A1), U4.37 (A_{7})
/A8: U3.9 (A8), U4.38 (A_{8})
/A9: U3.8 (A7), U4.39 (A_{9})
/A10: U3.7 (A6), U4.40 (A_{10})
/A11: U3.6 (A5), U4.1 (A_{11})
/A12: U3.5 (A4), U4.2 (A_{12})
/A13: U3.4 (A3), U4.3 (A_{13})
/A14: U3.3 (A2), U4.4 (A_{14})
/A15: U3.2 (A1), U4.5 (A_{15})
/BUS.A0: J1.5 (A0), U2.11 (B8)
/BUS.A1: J1.7 (A1), U2.12 (B7)
/BUS.A2: J1.9 (A2), U2.13 (B6)
/BUS.A3: J1.11 (A3), U2.14 (B5)
/BUS.A4: J1.13 (A4), U2.15 (B4)
/BUS.A5: J1.15 (A5), U2.16 (B3)
/BUS.A6: J1.17 (A6), U2.17 (B2)
/BUS.A7: J1.19 (A7), U2.18 (B1)
/BUS.A8: J1.21 (A8), U3.11 (B8)
/BUS.A9: J1.23 (A9), U3.12 (B7)
/BUS.A10: J1.25 (A10), U3.13 (B6)
/BUS.A11: J1.27 (A11), U3.14 (B5)
/BUS.A12: J1.29 (A12), U3.15 (B4)
/BUS.A13: J1.31 (A13), U3.16 (B3)
/BUS.A14: J1.33 (A14), U3.17 (B2)
/BUS.A15: J1.35 (A15), U3.18 (B1)
/BUS.D0: J1.6 (D0), U5.11 (B8)
/BUS.D1: J1.8 (D1), U5.12 (B7)
/BUS.D2: J1.10 (D2), U5.13 (B6)
/BUS.D3: J1.12 (D3), U5.14 (B5)
/BUS.D4: J1.14 (D4), U5.15 (B4)
/BUS.D5: J1.16 (D5), U5.16 (B3)
/BUS.D6: J1.18 (D6), U5.17 (B2)
/BUS.D7: J1.20 (D7), U5.18 (B1)
/BUS.~HALT~: J1.40 (~HALT~), U7.18 (B1)
/BUS.~IORQ~: J1.28 (~IORQ~), U7.15 (B4)
/BUS.~M1~: J1.30 (~M1~), U7.16 (B3)
/BUS.~MREQ~: J1.26 (~MREQ~), U7.14 (B5)
/BUS.~RD~: J1.22 (~RD~), U7.12 (B7)
/BUS.~RFSH~: J1.32 (~RFSH~), U7.17 (B2)
/BUS.~WR~: J1.24 (~WR~), U7.13 (B6)
/BUSAK: U1.4, U2.19 (~OE), U3.19 (~OE), U5.19 (~OE), U7.19 (~OE)
/CLK: J1.42 (CLK), J3.7, U4.6 (CLK)
/D0: U4.14 (D_{0}), U5.9 (A8)
/D1: U4.15 (D_{1}), U5.8 (A7)
/D2: U4.12 (D_{2}), U5.7 (A6)
/D3: U4.8 (D_{3}), U5.6 (A5)
/D4: U4.7 (D_{4}), U5.5 (A4)
/D5: U4.9 (D_{5}), U5.4 (A3)
/D6: U4.10 (D_{6}), U5.3 (A2)
/D7: U4.13 (D_{7}), U5.2 (A1)
/MCLK: J1.44 (MCLK), J3.5
/RUN: J2.4, J3.9, J4.6
/~BUSAK~: J1.62 (~BUSAK~), U1.2, U4.23 (~BUSACK)
/~BUSRQ~: J1.60 (~BUSRQ~), U4.25 (~BUSREQ)
/~HALT~: U4.18 (~HALT), U7.2 (A1)
/~INT~: J1.64 (~INT~), U4.16 (~INT)
/~IORQ~: U4.20 (~IORQ), U7.5 (A4)
/~M1~: U4.27 (~M1), U7.4 (A3)
/~MREQ~: U4.19 (~MREQ), U7.6 (A5)
/~NMI~: J1.36 (~NMI~), U4.17 (~NMI)
/~RD~: U4.21 (~RD), U5.1 (DIR), U7.8 (A7)
/~RESET_SW: J4.7, SW1.1, U6.3 (~MR)
/~RESET~: J1.39 (~RESET~), U4.26 (~RESET), U6.1 (~RST)
/~RFSH~: U4.28 (~RFSH), U7.3 (A2)
/~STEP: J2.2, J3.10, J4.8
/~WAIT~: J1.34 (~WAIT~), U4.24 (~WAIT)
/~WR~: U4.22 (~WR), U7.7 (A6)
GND: C1.2, C2.2, C3.2, C4.2, C5.2, C6.2, C7.2, C8.2, C9.2, D1.1 (K), J1.41 (GND), J1.43 (GND), J1.45 (GND), J1.46 (GND), J3.3, J3.4, J3.6, J3.8, J4.9, J4.10, SW1.2, U1.3 (GND), U2.10 (GND), U3.10 (GND), U4.29 (GND), U5.10 (GND), U6.2 (GND), U7.10 (GND)
unnamed: D1.2 (A), R1.2
unnamed: J1.80 (AUX), J2.1
unnamed: J1.79 (GPIO15), J2.3
unnamed: J1.37 (IEI), J1.38 (IEO)
unnamed: R2.2, U7.9 (A8)

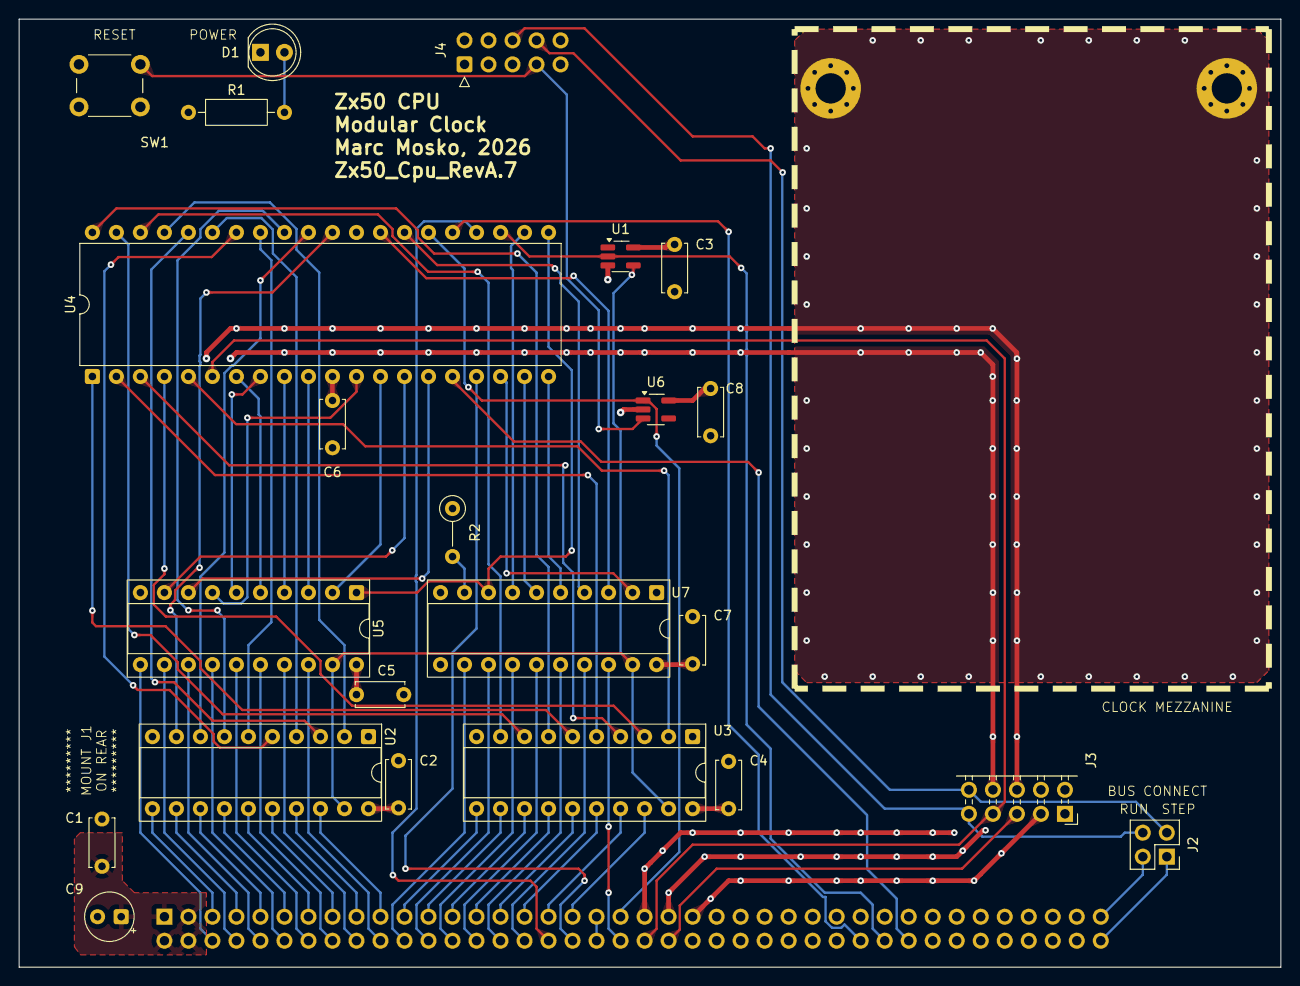
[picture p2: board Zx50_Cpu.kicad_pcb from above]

Board: 4 copper layers, 133.5 x 100.3 mm, 24 parts (1 on the bottom side), 81 nets.

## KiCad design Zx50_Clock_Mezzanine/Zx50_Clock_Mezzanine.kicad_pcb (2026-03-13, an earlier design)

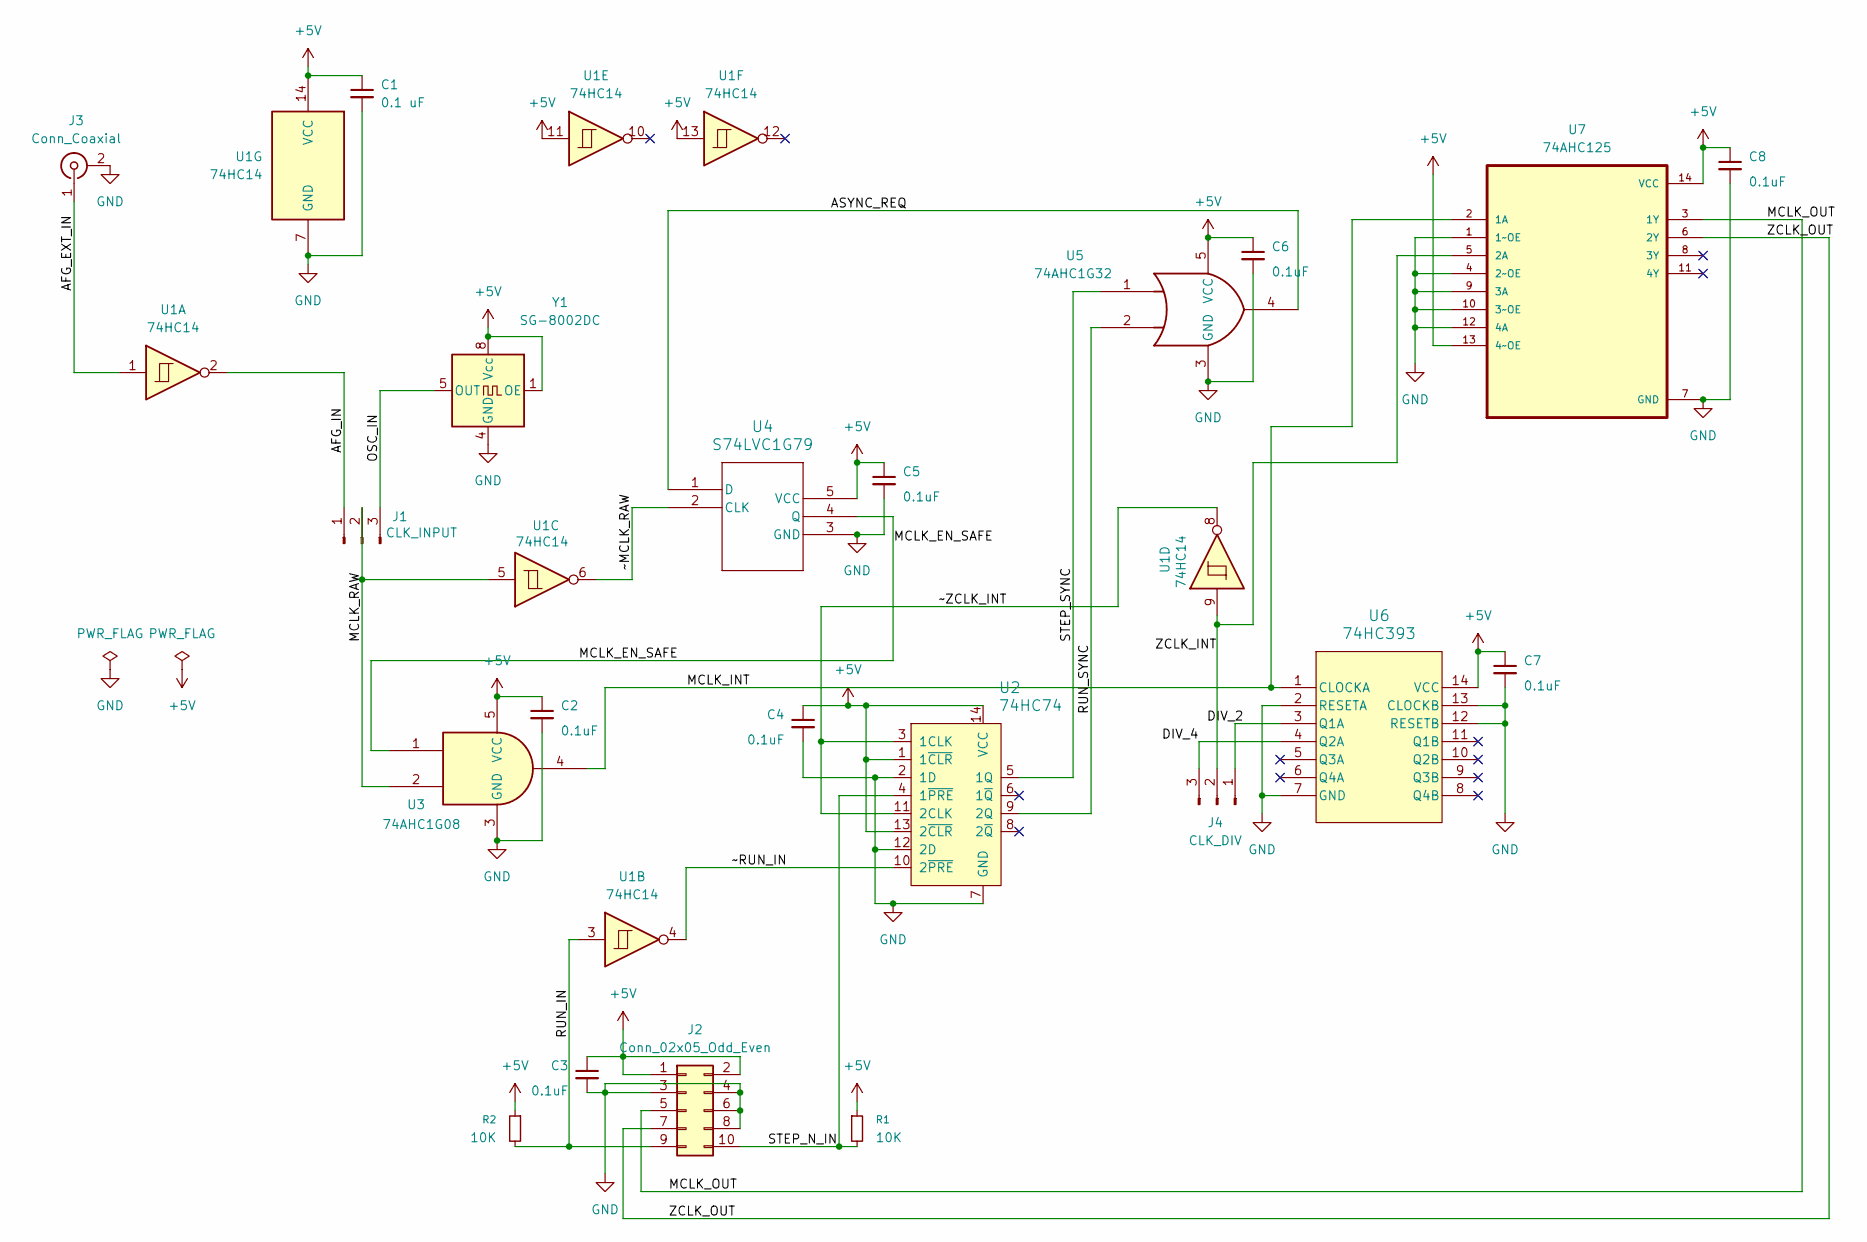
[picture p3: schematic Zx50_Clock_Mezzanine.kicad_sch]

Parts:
C1: 0.1 uF; C_0805_2012Metric_Pad1.18x1.45mm_HandSolder; DigiKey_PN 311-1140-1-ND
C2, C3, C4, C5, C6, C7, C8: 0.1uF; C_0805_2012Metric_Pad1.18x1.45mm_HandSolder; DigiKey_PN 311-1140-1-ND
J1: CLK_INPUT; PinHeader_1x03_P2.54mm_Vertical; DigiKey_PN 732-5316-ND
J2: Conn_02x05_Odd_Even; PinHeader_2x05_P2.54mm_Vertical; DigiKey_PN 2057-PH2RA-10-UA-ND
J3: Conn_Coaxial; BNC_Amphenol_B6252HB-NPP3G-50_Horizontal; DigiKey_PN ARF1178-ND
J4: CLK_DIV; PinHeader_1x03_P2.54mm_Vertical; DigiKey_PN 732-5316-ND
R1, R2: 10K; R_0805_2012Metric_Pad1.20x1.40mm_HandSolder; DigiKey_PN 311-10.0KCRCT-ND
U1: 74HC14; SOIC-14_3.9x8.7mm_P1.27mm; DigiKey_PN MC74HC14ADR2GOSCT-ND
U2: 74HC74; SOIC-14_3.9x8.7mm_P1.27mm; MPN SN74HC74N; Digi-Key_PN 296-1602-5-ND
U3: 74AHC1G08; SOT-23-5_HandSoldering; DigiKey_PN 296-1091-1-ND
U4: S74LVC1G79; SOT-23-5_HandSoldering; DigiKey_PN 296-9849-1-ND
U5: 74AHC1G32; SOT-23-5_HandSoldering; DigiKey_PN 296-1093-1-ND
U6: 74HC393; SOIC-14_3.9x8.7mm_P1.27mm; DigiKey_PN 296-8317-5-ND
U7: 74AHC125; SOIC-14_3.9x8.7mm_P1.27mm; DigiKey_PN 296-4530-1-ND
Y1: SG-8002DC; DIP-8_W7.62mm_Socket; DigiKey_PN 17-2485264-1-ND

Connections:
+5V: C1.1, C2.1, C3.1, C4.1, C5.1, C6.1, C7.1, C8.1, J2.1, J2.2, R1.1, R2.1, U1.11, U1.13, U1.14 (VCC), U2.1 (1~CLR), U2.13 (2~CLR), U2.14 (VCC), U3.5 (VCC), U4.5 (VCC), U5.5 (VCC), U6.14 (VCC), U7.13 (4~OE), U7.14 (VCC), Y1.1 (OE), Y1.8 (Vcc)
/AFG_EXT_IN: J3.1 (In), U1.1
/AFG_IN: J1.1, U1.2
/ASYNC_REQ: U4.1 (D), U5.4
/DIV_2: J4.1, U6.3 (Q1A)
/DIV_4: J4.3, U6.4 (Q2A)
/MCLK_EN_SAFE: U3.1, U4.4 (Q)
/MCLK_INT: U3.4, U6.1 (CLOCKA), U7.2 (1A)
/MCLK_OUT: J2.5, U7.3 (1Y)
/MCLK_RAW: J1.2, U1.5, U3.2
/OSC_IN: J1.3, Y1.5 (OUT)
/RUN_IN: J2.9, R2.2, U1.3
/RUN_SYNC: U2.9 (2Q), U5.2
/STEP_N_IN: J2.10, R1.2, U2.4 (1~PRE)
/STEP_SYNC: U2.5 (1Q), U5.1
/ZCLK_INT: J4.2, U1.9, U7.5 (2A)
/ZCLK_OUT: J2.7, U7.6 (2Y)
/~MCLK_RAW: U1.6, U4.2 (CLK)
/~RUN_IN: U1.4, U2.10 (2~PRE)
/~ZCLK_INT: U1.8, U2.3 (1CLK), U2.11 (2CLK)
GND: C1.2, C2.2, C3.2, C4.2, C5.2, C6.2, C7.2, C8.2, J2.3, J2.4, J2.6, J2.8, J3.2 (Ext), U1.7 (GND), U2.2 (1D), U2.7 (GND), U2.12 (2D), U3.3 (GND), U4.3 (GND), U5.3 (GND), U6.2 (RESETA), U6.7 (GND), U6.12 (RESETB), U6.13 (CLOCKB), U7.1 (1~OE), U7.4 (2~OE), U7.7 (GND), U7.9 (3A), U7.10 (3~OE), U7.12 (4A), Y1.4 (GND)

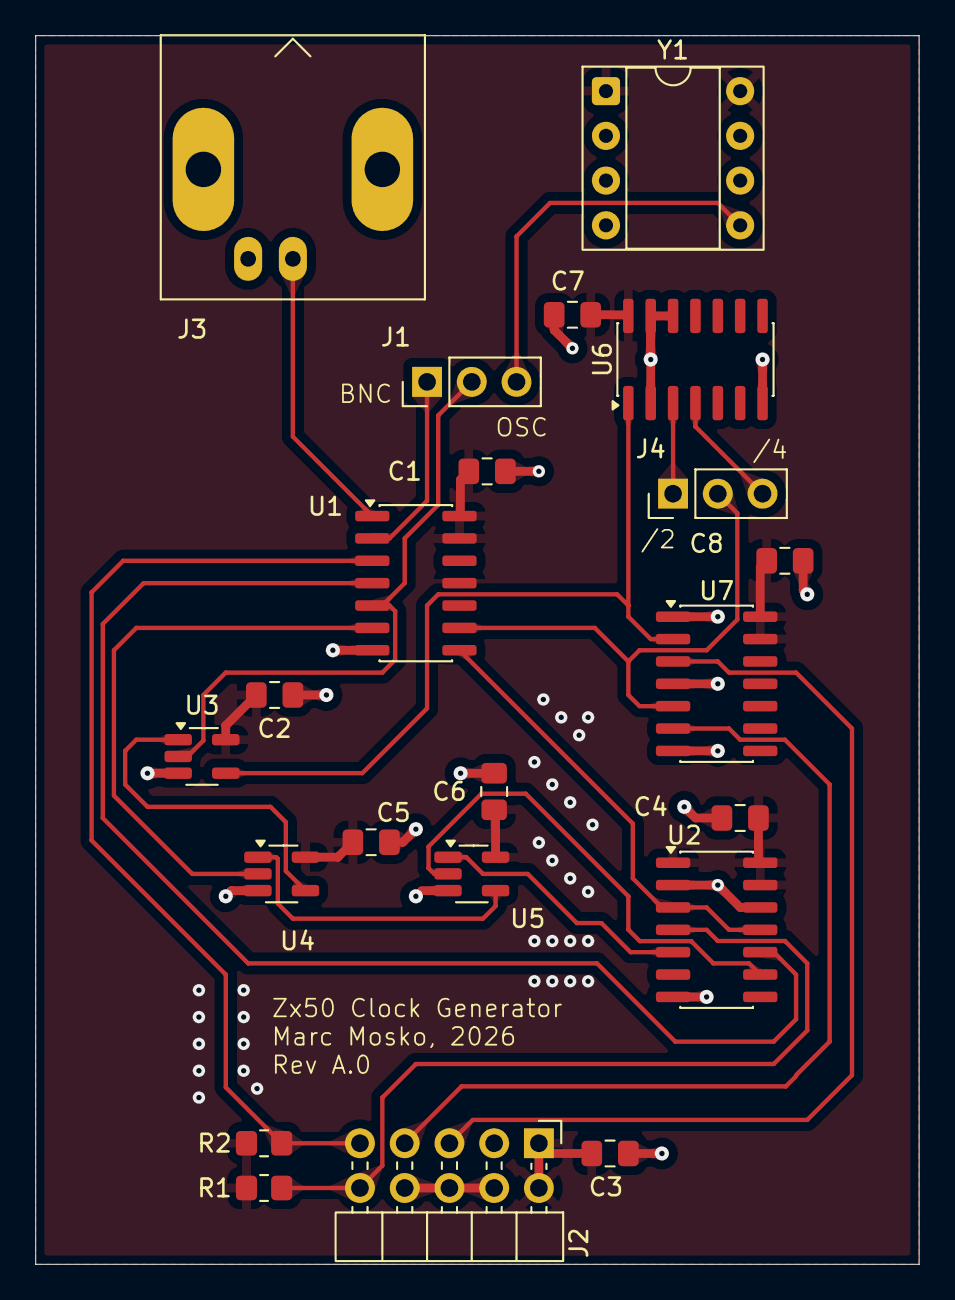
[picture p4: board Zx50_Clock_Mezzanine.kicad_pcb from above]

Board: 2 copper layers, 50.2 x 69.8 mm, 22 parts (0 on the bottom side), 21 nets.

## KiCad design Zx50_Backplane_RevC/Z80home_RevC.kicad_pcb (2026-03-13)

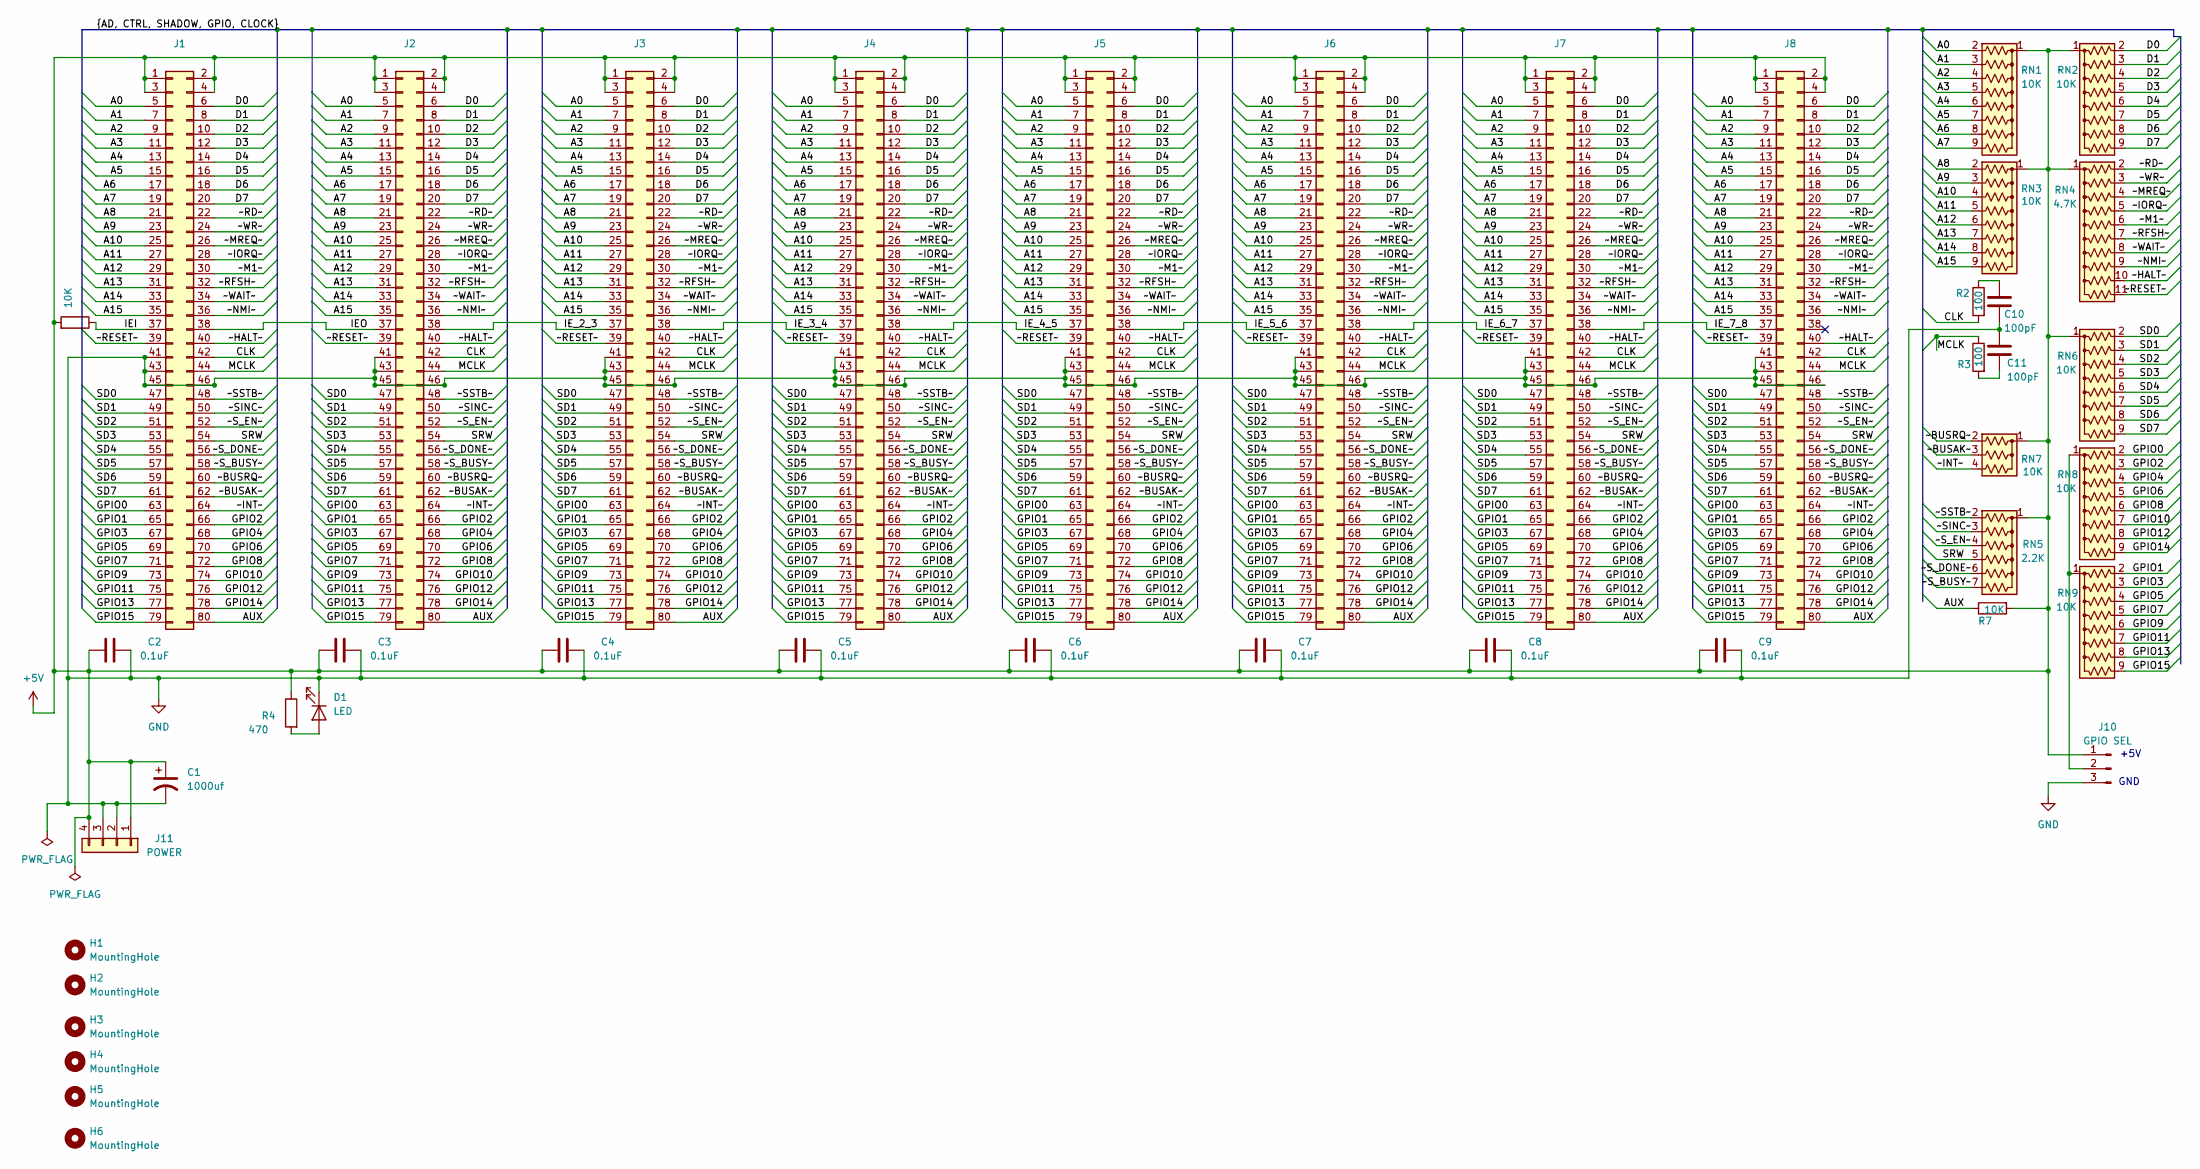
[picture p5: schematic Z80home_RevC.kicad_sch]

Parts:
C1: 1000uf; CP_Radial_D10.0mm_P5.00mm; DigiKey_PN 493-15895-ND
C2, C3, C4, C5, C6, C7, C8, C9: 0.1uF; C_Disc_D5.0mm_W2.5mm_P5.00mm
C10, C11: 100pF; C_Disc_D5.0mm_W2.5mm_P5.00mm; DigiKey_PN 399-4264-ND
D1: LED; LED_D5.0mm; DigiKey_PN 732-5016-ND
H1, H2, H3, H4, H5, H6: MountingHole; MountingHole_3.2mm_M3; DigiKey_PN SJ5003-0-ND
J1, J2, J3, J4, J5, J6, J7, J8: Conn_02x40_Odd_Even; PinSocket_2x40_P2.54mm_Vertical_Oval; DigiKey_PN SAM1179-40-ND
J10: GPIO SEL; PinHeader_1x03_P2.54mm_Vertical; DigiKey_PN 732-5316-ND
J11: POWER; TerminalBlock_Phoenix_MKDS-1,5-4-5.08_1x04_P5.08mm_Horizont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; DigiKey_PN 277-1238-ND
R1: 10K; R_Axial_DIN0207_L6.3mm_D2.5mm_P10.16mm_Horizontal
R2, R3: 100; R_Axial_DIN0207_L6.3mm_D2.5mm_P10.16mm_Horizontal
R4: 470; R_Axial_DIN0207_L6.3mm_D2.5mm_P10.16mm_Horizontal
R7: 10K; R_Axial_DIN0207_L6.3mm_D2.5mm_P5.08mm_Vertical
RN1, RN2, RN3, RN6, RN8, RN9: 10K; R_Array_SIP9; DigiKey_PN 4609X-101-103LF-ND
RN4: 4.7K; R_Array_SIP11; DigiKey_PN 4611X-101-472LF-ND
RN5: 2.2K; R_Array_SIP7; DigiKey_PN 4607X-101-222LF-ND
RN7: 10K; R_Array_SIP4; DigiKey_PN 4604X-101-103LF-ND

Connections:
+5V: C1.1, C2.1, C3.1, C4.1, C5.1, C6.1, C7.1, C8.1, C9.1, J1.1, J1.2, J1.3, J1.4, J2.1, J2.2, J2.3, J2.4, J3.1, J3.2, J3.3, J3.4, J4.1, J4.2, J4.3, J4.4, J5.1, J5.2, J5.3, J5.4, J6.1, J6.2, J6.3, J6.4, J7.1, J7.2, J7.3, J7.4, J8.1, J8.2, J8.3, J8.4, J10.1, J11.1, J11.4, R1.2, R4.1, R7.2, RN1.1 (common), RN2.1 (common), RN3.1 (common), RN4.1 (common), RN5.1 (common), RN6.1 (common), RN7.1 (common)
/A0: J1.5, J2.5, J3.5, J4.5, J5.5, J6.5, J7.5, J8.5, RN1.2 (R1)
/A1: J1.7, J2.7, J3.7, J4.7, J5.7, J6.7, J7.7, J8.7, RN1.3 (R2)
/A2: J1.9, J2.9, J3.9, J4.9, J5.9, J6.9, J7.9, J8.9, RN1.4 (R3)
/A3: J1.11, J2.11, J3.11, J4.11, J5.11, J6.11, J7.11, J8.11, RN1.5 (R4)
/A4: J1.13, J2.13, J3.13, J4.13, J5.13, J6.13, J7.13, J8.13, RN1.6 (R5)
/A5: J1.15, J2.15, J3.15, J4.15, J5.15, J6.15, J7.15, J8.15, RN1.7 (R6)
/A6: J1.17, J2.17, J3.17, J4.17, J5.17, J6.17, J7.17, J8.17, RN1.8 (R7)
/A7: J1.19, J2.19, J3.19, J4.19, J5.19, J6.19, J7.19, J8.19, RN1.9 (R8)
/A8: J1.21, J2.21, J3.21, J4.21, J5.21, J6.21, J7.21, J8.21, RN3.2 (R1)
/A9: J1.23, J2.23, J3.23, J4.23, J5.23, J6.23, J7.23, J8.23, RN3.3 (R2)
/A10: J1.25, J2.25, J3.25, J4.25, J5.25, J6.25, J7.25, J8.25, RN3.4 (R3)
/A11: J1.27, J2.27, J3.27, J4.27, J5.27, J6.27, J7.27, J8.27, RN3.5 (R4)
/A12: J1.29, J2.29, J3.29, J4.29, J5.29, J6.29, J7.29, J8.29, RN3.6 (R5)
/A13: J1.31, J2.31, J3.31, J4.31, J5.31, J6.31, J7.31, J8.31, RN3.7 (R6)
/A14: J1.33, J2.33, J3.33, J4.33, J5.33, J6.33, J7.33, J8.33, RN3.8 (R7)
/A15: J1.35, J2.35, J3.35, J4.35, J5.35, J6.35, J7.35, J8.35, RN3.9 (R8)
/AUX: J1.80, J2.80, J3.80, J4.80, J5.80, J6.80, J7.80, J8.80, R7.1
/CLK: J1.42, J2.42, J3.42, J4.42, J5.42, J6.42, J7.42, J8.42, R2.2
/D0: J1.6, J2.6, J3.6, J4.6, J5.6, J6.6, J7.6, J8.6, RN2.2 (R1)
/D1: J1.8, J2.8, J3.8, J4.8, J5.8, J6.8, J7.8, J8.8, RN2.3 (R2)
/D2: J1.10, J2.10, J3.10, J4.10, J5.10, J6.10, J7.10, J8.10, RN2.4 (R3)
/D3: J1.12, J2.12, J3.12, J4.12, J5.12, J6.12, J7.12, J8.12, RN2.5 (R4)
/D4: J1.14, J2.14, J3.14, J4.14, J5.14, J6.14, J7.14, J8.14, RN2.6 (R5)
/D5: J1.16, J2.16, J3.16, J4.16, J5.16, J6.16, J7.16, J8.16, RN2.7 (R6)
/D6: J1.18, J2.18, J3.18, J4.18, J5.18, J6.18, J7.18, J8.18, RN2.8 (R7)
/D7: J1.20, J2.20, J3.20, J4.20, J5.20, J6.20, J7.20, J8.20, RN2.9 (R8)
/GPIO0: J1.63, J2.63, J3.63, J4.63, J5.63, J6.63, J7.63, J8.63, RN8.2 (R1)
/GPIO1: J1.65, J2.65, J3.65, J4.65, J5.65, J6.65, J7.65, J8.65, RN9.2 (R1)
/GPIO2: J1.66, J2.66, J3.66, J4.66, J5.66, J6.66, J7.66, J8.66, RN8.3 (R2)
/GPIO3: J1.67, J2.67, J3.67, J4.67, J5.67, J6.67, J7.67, J8.67, RN9.3 (R2)
/GPIO4: J1.68, J2.68, J3.68, J4.68, J5.68, J6.68, J7.68, J8.68, RN8.4 (R3)
/GPIO5: J1.69, J2.69, J3.69, J4.69, J5.69, J6.69, J7.69, J8.69, RN9.4 (R3)
/GPIO6: J1.70, J2.70, J3.70, J4.70, J5.70, J6.70, J7.70, J8.70, RN8.5 (R4)
/GPIO7: J1.71, J2.71, J3.71, J4.71, J5.71, J6.71, J7.71, J8.71, RN9.5 (R4)
/GPIO8: J1.72, J2.72, J3.72, J4.72, J5.72, J6.72, J7.72, J8.72, RN8.6 (R5)
/GPIO9: J1.73, J2.73, J3.73, J4.73, J5.73, J6.73, J7.73, J8.73, RN9.6 (R5)
/GPIO10: J1.74, J2.74, J3.74, J4.74, J5.74, J6.74, J7.74, J8.74, RN8.7 (R6)
/GPIO11: J1.75, J2.75, J3.75, J4.75, J5.75, J6.75, J7.75, J8.75, RN9.7 (R6)
/GPIO12: J1.76, J2.76, J3.76, J4.76, J5.76, J6.76, J7.76, J8.76, RN8.8 (R7)
/GPIO13: J1.77, J2.77, J3.77, J4.77, J5.77, J6.77, J7.77, J8.77, RN9.8 (R7)
/GPIO14: J1.78, J2.78, J3.78, J4.78, J5.78, J6.78, J7.78, J8.78, RN8.9 (R8)
/GPIO15: J1.79, J2.79, J3.79, J4.79, J5.79, J6.79, J7.79, J8.79, RN9.9 (R8)
/IEI: J1.37, R1.1
/IEO: J1.38, J2.37
/IE_2_3: J2.38, J3.37
/IE_3_4: J3.38, J4.37
/IE_4_5: J4.38, J5.37
/IE_5_6: J5.38, J6.37
/IE_6_7: J6.38, J7.37
/IE_7_8: J7.38, J8.37
/MCLK: J1.44, J2.44, J3.44, J4.44, J5.44, J6.44, J7.44, J8.44, R3.1
/SD0: J1.47, J2.47, J3.47, J4.47, J5.47, J6.47, J7.47, J8.47, RN6.2 (R1)
/SD1: J1.49, J2.49, J3.49, J4.49, J5.49, J6.49, J7.49, J8.49, RN6.3 (R2)
/SD2: J1.51, J2.51, J3.51, J4.51, J5.51, J6.51, J7.51, J8.51, RN6.4 (R3)
/SD3: J1.53, J2.53, J3.53, J4.53, J5.53, J6.53, J7.53, J8.53, RN6.5 (R4)
/SD4: J1.55, J2.55, J3.55, J4.55, J5.55, J6.55, J7.55, J8.55, RN6.6 (R5)
/SD5: J1.57, J2.57, J3.57, J4.57, J5.57, J6.57, J7.57, J8.57, RN6.7 (R6)
/SD6: J1.59, J2.59, J3.59, J4.59, J5.59, J6.59, J7.59, J8.59, RN6.8 (R7)
/SD7: J1.61, J2.61, J3.61, J4.61, J5.61, J6.61, J7.61, J8.61, RN6.9 (R8)
/SRW: J1.54, J2.54, J3.54, J4.54, J5.54, J6.54, J7.54, J8.54, RN5.5 (R4)
/~BUSAK~: J1.62, J2.62, J3.62, J4.62, J5.62, J6.62, J7.62, J8.62, RN7.3 (R2)
/~BUSRQ~: J1.60, J2.60, J3.60, J4.60, J5.60, J6.60, J7.60, J8.60, RN7.2 (R1)
/~HALT~: J1.40, J2.40, J3.40, J4.40, J5.40, J6.40, J7.40, J8.40, RN4.10 (R9)
/~INT~: J1.64, J2.64, J3.64, J4.64, J5.64, J6.64, J7.64, J8.64, RN7.4 (R3)
/~IORQ~: J1.28, J2.28, J3.28, J4.28, J5.28, J6.28, J7.28, J8.28, RN4.5 (R4)
/~M1~: J1.30, J2.30, J3.30, J4.30, J5.30, J6.30, J7.30, J8.30, RN4.6 (R5)
/~MREQ~: J1.26, J2.26, J3.26, J4.26, J5.26, J6.26, J7.26, J8.26, RN4.4 (R3)
/~NMI~: J1.36, J2.36, J3.36, J4.36, J5.36, J6.36, J7.36, J8.36, RN4.9 (R8)
/~RD~: J1.22, J2.22, J3.22, J4.22, J5.22, J6.22, J7.22, J8.22, RN4.2 (R1)
/~RESET~: J1.39, J2.39, J3.39, J4.39, J5.39, J6.39, J7.39, J8.39, RN4.11 (R10)
/~RFSH~: J1.32, J2.32, J3.32, J4.32, J5.32, J6.32, J7.32, J8.32, RN4.7 (R6)
/~SINC~: J1.50, J2.50, J3.50, J4.50, J5.50, J6.50, J7.50, J8.50, RN5.3 (R2)
/~SSTB~: J1.48, J2.48, J3.48, J4.48, J5.48, J6.48, J7.48, J8.48, RN5.2 (R1)
/~S_BUSY~: J1.58, J2.58, J3.58, J4.58, J5.58, J6.58, J7.58, J8.58, RN5.7 (R6)
/~S_DONE~: J1.56, J2.56, J3.56, J4.56, J5.56, J6.56, J7.56, J8.56, RN5.6 (R5)
/~S_EN~: J1.52, J2.52, J3.52, J4.52, J5.52, J6.52, J7.52, J8.52, RN5.4 (R3)
/~WAIT~: J1.34, J2.34, J3.34, J4.34, J5.34, J6.34, J7.34, J8.34, RN4.8 (R7)
/~WR~: J1.24, J2.24, J3.24, J4.24, J5.24, J6.24, J7.24, J8.24, RN4.3 (R2)
GND: C1.2, C2.2, C3.2, C4.2, C5.2, C6.2, C7.2, C8.2, C9.2, C10.2, C11.1, D1.1 (K), J1.41, J1.43, J1.45, J1.46, J2.41, J2.43, J2.45, J2.46, J3.41, J3.43, J3.45, J3.46, J4.41, J4.43, J4.45, J4.46, J5.41, J5.43, J5.45, J5.46, J6.41, J6.43, J6.45, J6.46, J7.41, J7.43, J7.45, J7.46, J8.41, J8.43, J8.45, J8.46, J10.3, J11.2, J11.3
unnamed: C10.1, R2.1
unnamed: C11.2, R3.2
unnamed: D1.2 (A), R4.2
unnamed: J10.2, RN8.1 (common), RN9.1 (common)

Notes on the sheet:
+5V
GND

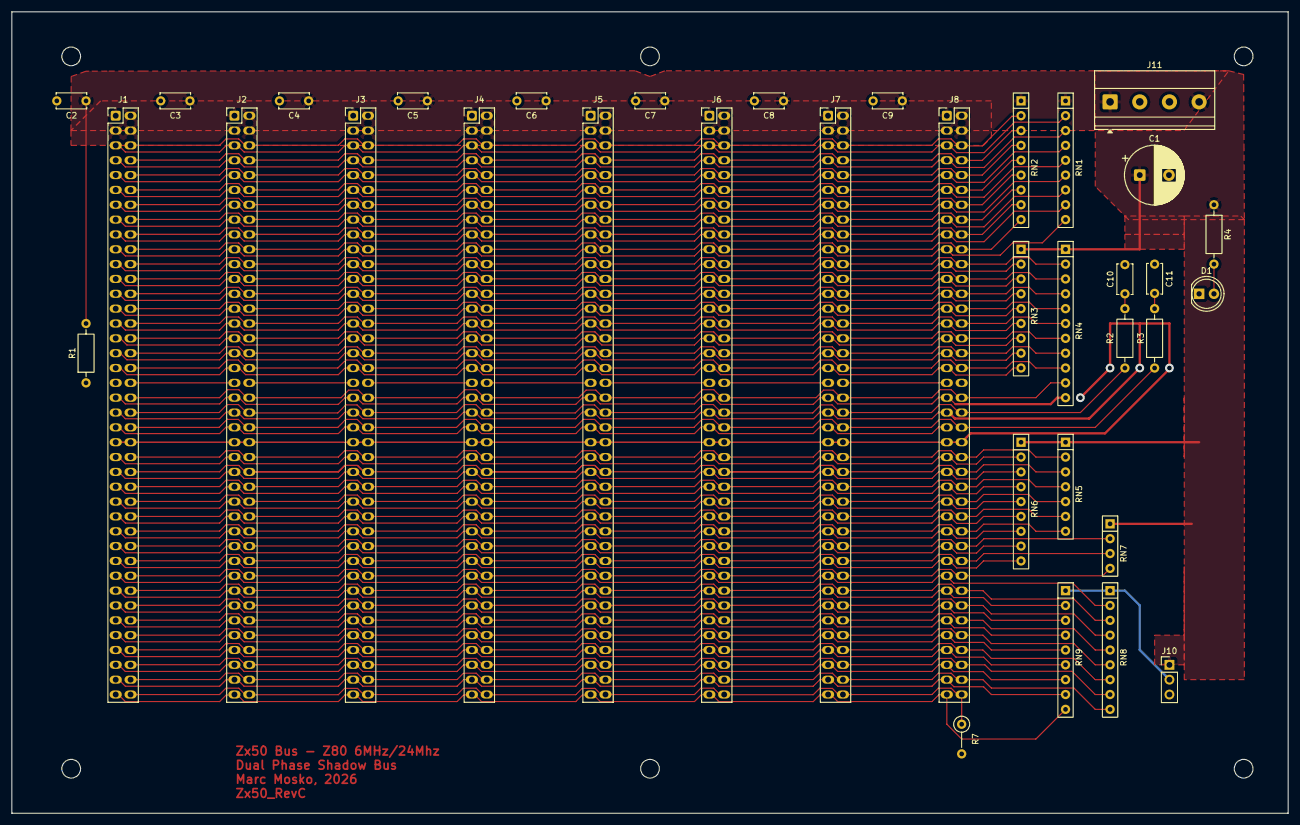
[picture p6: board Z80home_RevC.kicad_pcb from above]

Board: 2 copper layers, 218.4 x 137.2 mm, 42 parts (0 on the bottom side), 84 nets.

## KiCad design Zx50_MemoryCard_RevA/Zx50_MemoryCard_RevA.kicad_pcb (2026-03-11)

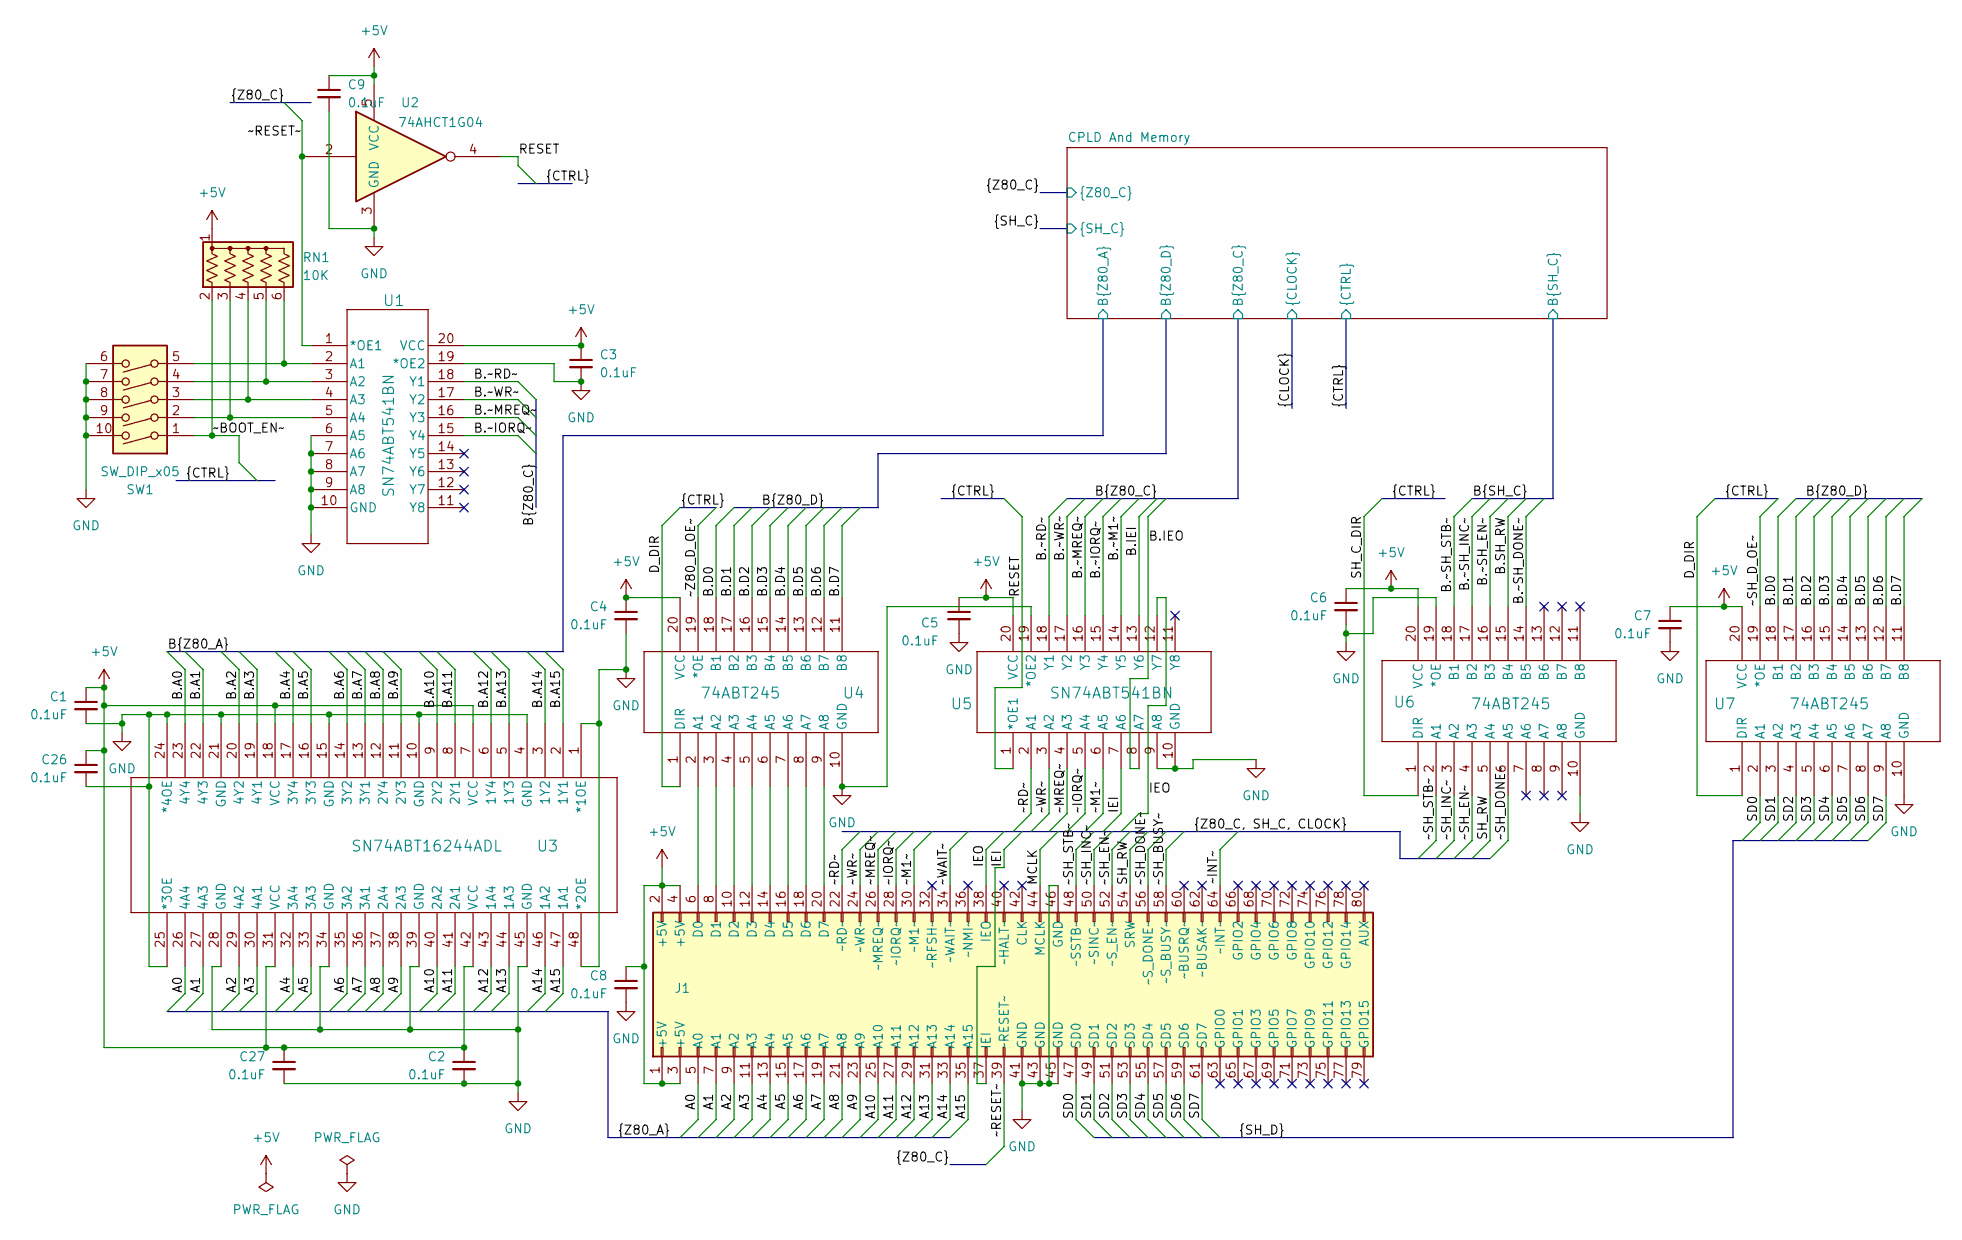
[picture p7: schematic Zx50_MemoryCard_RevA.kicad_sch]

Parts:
C1, C2, C3, C4, C5, C6, C7, C8, C9, C26, C27: 0.1uF; C_0603_1608Metric; LCSC C14663
J1: Zx50_EdgeConnector; PinSocket_2x40_P2.54mm_Horizontal_Edge; DigiKey_PN 2057-PH2RA-80-UA-ND
RN1: 10K; R_Array_SIP6; LCSC 4606X-AP1-103LF
SW1: SW_DIP_x05; SW_DIP_SPSTx05_Slide_9.78x14.88mm_W7.62mm_P2.54mm; LCSC 208-5
U1, U5: SN74ABT541BN; TSSOP-20_4.4x6.5mm_P0.65mm; LCSC C131956
U2: 74AHCT1G04; SOT-23-5; LCSC C52140419
U3: SN74ABT16244ADL; SSOP-48_7.5x15.9mm_P0.635mm; LCSC C2869608
U4, U6, U7: 74ABT245; SOIC-20W_7.5x12.8mm_P1.27mm; LCSC C1548132

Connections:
+5V: C1.1, C2.1, C3.1, C4.1, C5.1, C6.1, C7.1, C8.1, C9.1, C26.1, C27.1, J1.1 (+5V), J1.2 (+5V), J1.3 (+5V), J1.4 (+5V), RN1.1 (common), U1.20 (VCC), U2.5 (VCC), U3.7 (VCC), U3.18 (VCC), U3.31 (VCC), U3.42 (VCC), U4.20 (VCC), U5.20 (VCC), U6.20 (VCC), U7.20 (VCC); also elsewhere on the board
/A0: J1.5 (A0), U3.26 (4A4)
/A1: J1.7 (A1), U3.27 (4A3)
/A2: J1.9 (A2), U3.29 (4A2)
/A3: J1.11 (A3), U3.30 (4A1)
/A4: J1.13 (A4), U3.32 (3A4)
/A5: J1.15 (A5), U3.33 (3A3)
/A6: J1.17 (A6), U3.35 (3A2)
/A7: J1.19 (A7), U3.36 (3A1)
/A8: J1.21 (A8), U3.37 (2A4)
/A9: J1.23 (A9), U3.38 (2A3)
/A10: J1.25 (A10), U3.40 (2A2)
/A11: J1.27 (A11), U3.41 (2A1)
/A12: J1.29 (A12), U3.43 (1A4)
/A13: J1.31 (A13), U3.44 (1A3)
/A14: J1.33 (A14), U3.46 (1A2)
/A15: J1.35 (A15), U3.47 (1A1)
/B.A0: U3.23 (4Y4); also elsewhere on the board
/B.A1: U3.22 (4Y3); also elsewhere on the board
/B.A2: U3.20 (4Y2); also elsewhere on the board
/B.A3: U3.19 (4Y1); also elsewhere on the board
/B.A4: U3.17 (3Y4); also elsewhere on the board
/B.A5: U3.16 (3Y3); also elsewhere on the board
/B.A6: U3.14 (3Y2); also elsewhere on the board
/B.A7: U3.13 (3Y1); also elsewhere on the board
/B.A8: U3.12 (2Y4); also elsewhere on the board
/B.A9: U3.11 (2Y3); also elsewhere on the board
/B.A10: U3.9 (2Y2); also elsewhere on the board
/B.A11: U3.8 (2Y1); also elsewhere on the board
/B.A12: U3.6 (1Y4); also elsewhere on the board
/B.A13: U3.5 (1Y3); also elsewhere on the board
/B.A14: U3.3 (1Y2); also elsewhere on the board
/B.A15: U3.2 (1Y1); also elsewhere on the board
/B.D0: U4.18 (B1), U7.18 (B1); also elsewhere on the board
/B.D1: U4.17 (B2), U7.17 (B2); also elsewhere on the board
/B.D2: U4.16 (B3), U7.16 (B3); also elsewhere on the board
/B.D3: U4.15 (B4), U7.15 (B4); also elsewhere on the board
/B.D4: U4.14 (B5), U7.14 (B5); also elsewhere on the board
/B.D5: U4.13 (B6), U7.13 (B6); also elsewhere on the board
/B.D6: U4.12 (B7), U7.12 (B7); also elsewhere on the board
/B.D7: U4.11 (B8), U7.11 (B8); also elsewhere on the board
/B.IEI: U5.13 (Y6); also elsewhere on the board
/B.IEO: U5.8 (A7); also elsewhere on the board
/B.SH_RW: U6.15 (B4); also elsewhere on the board
/B.~IORQ~: U1.15 (Y4), U5.15 (Y4); also elsewhere on the board
/B.~M1~: U5.14 (Y5); also elsewhere on the board
/B.~MREQ~: U1.16 (Y3), U5.16 (Y3); also elsewhere on the board
/B.~RD~: U1.18 (Y1), U5.18 (Y1); also elsewhere on the board
/B.~SH_DONE~: U6.14 (B5); also elsewhere on the board
/B.~SH_EN~: U6.16 (B3); also elsewhere on the board
/B.~SH_INC~: U6.17 (B2); also elsewhere on the board
/B.~SH_STB~: U6.18 (B1); also elsewhere on the board
/B.~WR~: U1.17 (Y2), U5.17 (Y2); also elsewhere on the board
/D_DIR: U4.1 (DIR), U7.1 (DIR); also elsewhere on the board
/IEI: J1.37 (IEI), U5.7 (A6)
/IEO: J1.38 (IEO), U5.12 (Y7)
/MCLK: J1.44 (MCLK); also elsewhere on the board
/RESET: U2.4, U5.1 (*OE1)
/SD0: J1.47 (SD0), U7.2 (A1)
/SD1: J1.49 (SD1), U7.3 (A2)
/SD2: J1.51 (SD2), U7.4 (A3)
/SD3: J1.53 (SD3), U7.5 (A4)
/SD4: J1.55 (SD4), U7.6 (A5)
/SD5: J1.57 (SD5), U7.7 (A6)
/SD6: J1.59 (SD6), U7.8 (A7)
/SD7: J1.61 (SD7), U7.9 (A8)
/SH_C_DIR: U6.1 (DIR); also elsewhere on the board
/SH_RW: J1.54 (SRW), U6.5 (A4)
/~BOOT_EN~: RN1.2 (R1), SW1.1; also elsewhere on the board
/~INT~: J1.64 (~INT~); also elsewhere on the board
/~IORQ~: J1.28 (~IORQ~), U5.5 (A4)
/~M1~: J1.30 (~M1~), U5.6 (A5)
/~MREQ~: J1.26 (~MREQ~), U5.4 (A3)
/~RD~: J1.22 (~RD~), U5.2 (A1)
/~RESET~: J1.39 (~RESET~), U1.1 (*OE1), U2.2; also elsewhere on the board
/~SH_BUSY~: J1.58 (~S_BUSY~); also elsewhere on the board
/~SH_DONE~: J1.56 (~S_DONE~), U6.6 (A5)
/~SH_D_OE~: U7.19 (*OE); also elsewhere on the board
/~SH_EN~: J1.52 (~S_EN~), U6.4 (A3)
/~SH_INC~: J1.50 (~SINC~), U6.3 (A2)
/~SH_STB~: J1.48 (~SSTB~), U6.2 (A1)
/~WAIT~: J1.34 (~WAIT~); also elsewhere on the board
/~WR~: J1.24 (~WR~), U5.3 (A2)
/~Z80_D_OE~: U4.19 (*OE); also elsewhere on the board
GND: C1.2, C2.2, C3.2, C4.2, C5.2, C6.2, C7.2, C8.2, C9.2, C26.2, C27.2, J1.41 (GND), J1.43 (GND), J1.45 (GND), J1.46 (GND), SW1.6, SW1.7, SW1.8, SW1.9, SW1.10, U1.6 (A5), U1.7 (A6), U1.8 (A7), U1.9 (A8), U1.10 (GND), U1.19 (*OE2), U2.3 (GND), U3.1 (*1OE), U3.4 (GND), U3.10 (GND), U3.15 (GND), U3.21 (GND), U3.24 (*4OE), U3.25 (*3OE), U3.28 (GND), U3.34 (GND), U3.39 (GND), U3.45 (GND), U3.48 (*2OE), U4.10 (GND), U5.9 (A8), U5.10 (GND), U5.19 (*OE2), U6.10 (GND), U6.19 (*OE), U7.10 (GND); also elsewhere on the board
unnamed: J1.6 (D0), U4.2 (A1)
unnamed: J1.8 (D1), U4.3 (A2)
unnamed: J1.10 (D2), U4.4 (A3)
unnamed: J1.12 (D3), U4.5 (A4)
unnamed: J1.14 (D4), U4.6 (A5)
unnamed: J1.16 (D5), U4.7 (A6)
unnamed: J1.18 (D6), U4.8 (A7)
unnamed: J1.20 (D7), U4.9 (A8)
unnamed: RN1.3 (R2), SW1.2, U1.5 (A4)
unnamed: RN1.4 (R3), SW1.3, U1.4 (A3)
unnamed: RN1.5 (R4), SW1.4, U1.3 (A2)
unnamed: RN1.6 (R5), SW1.5, U1.2 (A1)

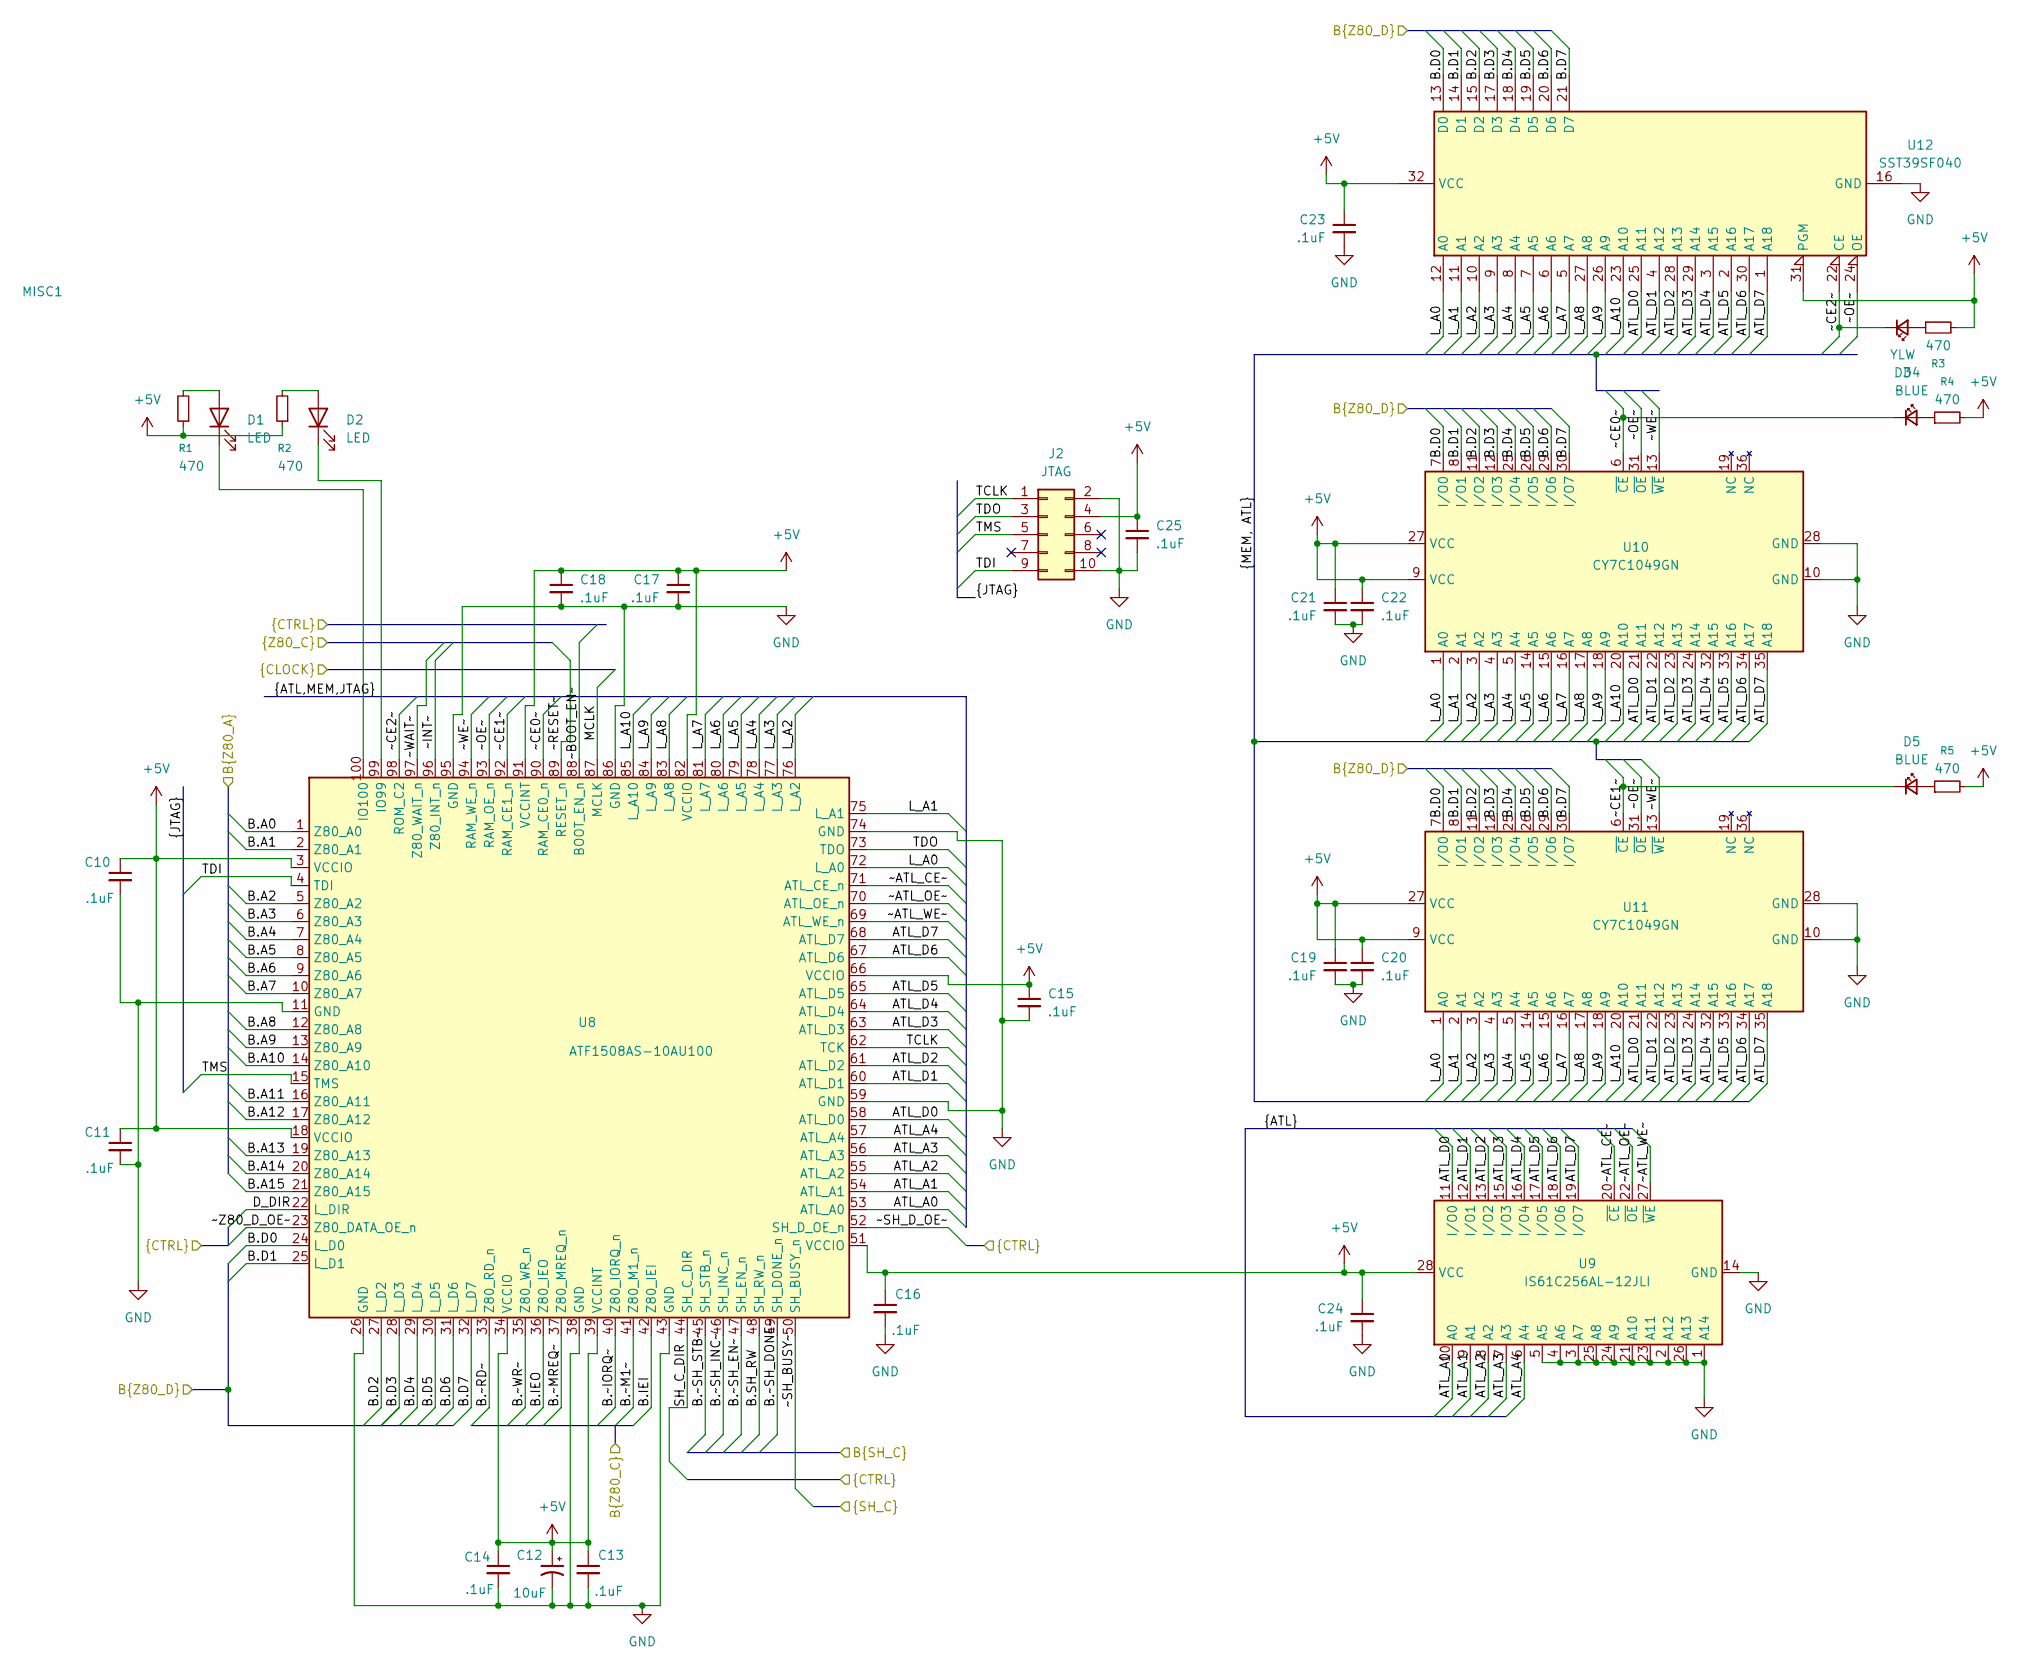
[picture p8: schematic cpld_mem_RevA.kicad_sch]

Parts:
C10, C11, C13, C14, C15, C16, C17, C18, C19, C20, C21, C22, C23, C24, C25: .1uF; C_0603_1608Metric; LCSC C14663
C12: 10uF; CP_Radial_Tantal_D5.0mm_P2.50mm
D1, D2: LED; LED_D3.0mm_Horizontal_O1.27mm_Z2.0mm
D3: YLW; LED_0805_2012Metric; LCSC C2296
D4, D5: BLUE; LED_0805_2012Metric; LCSC C2293
J2: JTAG; IDC-Header_2x05_P2.54mm_Vertical; DigiKey_PN 732-2094-ND
MISC1: DIP-32 socket; DigiKey_PN 123-AR32-HZL/01-TT-ND
R1, R2: 470; R_Axial_DIN0207_L6.3mm_D2.5mm_P7.62mm_Horizontal
R3, R4, R5: 470; R_0805_2012Metric; LCSC C17710
U8: ATF1508AS-10AU100; TQFP-100_14x14mm_P0.5mm; LCSC C31179
U9: IS61C256AL-12JLI; SOJ-28_7.62x18.415mm_P1.27mm; LCSC C2062861
U10, U11: CY7C1049GN; SOJ-36_10.16x23.495mm_P1.27mm; LCSC C2955765
U12: SST39SF040; DIP-32_W15.24mm_Socket; DigiKey_PN SST39SF040-70-4C-PHE-ND

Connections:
+5V: C10.1, C11.1, C12.1, C13.1, C14.1, C15.1, C16.1, C17.1, C18.1, C19.1, C20.1, C21.1, C22.1, C23.1, C24.1, C25.1, J2.4, R1.1, R2.1, R3.2, R4.2, R5.2, U8.3 (VCCIO), U8.18 (VCCIO), U8.34 (VCCIO), U8.39 (VCCINT), U8.51 (VCCIO), U8.66 (VCCIO), U8.82 (VCCIO), U8.91 (VCCINT), U9.28 (VCC), U10.9 (VCC), U10.27 (VCC), U11.9 (VCC), U11.27 (VCC), U12.31 (PGM), U12.32 (VCC); also elsewhere on the board
/B.A0: U8.1 (Z80_A0); also elsewhere on the board
/B.A1: U8.2 (Z80_A1); also elsewhere on the board
/B.A2: U8.5 (Z80_A2); also elsewhere on the board
/B.A3: U8.6 (Z80_A3); also elsewhere on the board
/B.A4: U8.7 (Z80_A4); also elsewhere on the board
/B.A5: U8.8 (Z80_A5); also elsewhere on the board
/B.A6: U8.9 (Z80_A6); also elsewhere on the board
/B.A7: U8.10 (Z80_A7); also elsewhere on the board
/B.A8: U8.12 (Z80_A8); also elsewhere on the board
/B.A9: U8.13 (Z80_A9); also elsewhere on the board
/B.A10: U8.14 (Z80_A10); also elsewhere on the board
/B.A11: U8.16 (Z80_A11); also elsewhere on the board
/B.A12: U8.17 (Z80_A12); also elsewhere on the board
/B.A13: U8.19 (Z80_A13); also elsewhere on the board
/B.A14: U8.20 (Z80_A14); also elsewhere on the board
/B.A15: U8.21 (Z80_A15); also elsewhere on the board
/B.D0: U8.24 (L_D0), U10.7 (I/O0), U11.7 (I/O0), U12.13 (D0); also elsewhere on the board
/B.D1: U8.25 (L_D1), U10.8 (I/O1), U11.8 (I/O1), U12.14 (D1); also elsewhere on the board
/B.D2: U8.27 (L_D2), U10.11 (I/O2), U11.11 (I/O2), U12.15 (D2); also elsewhere on the board
/B.D3: U8.28 (L_D3), U10.12 (I/O3), U11.12 (I/O3), U12.17 (D3); also elsewhere on the board
/B.D4: U8.29 (L_D4), U10.25 (I/O4), U11.25 (I/O4), U12.18 (D4); also elsewhere on the board
/B.D5: U8.30 (L_D5), U10.26 (I/O5), U11.26 (I/O5), U12.19 (D5); also elsewhere on the board
/B.D6: U8.31 (L_D6), U10.29 (I/O6), U11.29 (I/O6), U12.20 (D6); also elsewhere on the board
/B.D7: U8.32 (L_D7), U10.30 (I/O7), U11.30 (I/O7), U12.21 (D7); also elsewhere on the board
/B.IEI: U8.42 (Z80_IEI); also elsewhere on the board
/B.IEO: U8.36 (Z80_IEO); also elsewhere on the board
/B.SH_RW: U8.48 (SH_RW_n); also elsewhere on the board
/B.~IORQ~: U8.40 (Z80_IORQ_n); also elsewhere on the board
/B.~M1~: U8.41 (Z80_M1_n); also elsewhere on the board
/B.~MREQ~: U8.37 (Z80_MREQ_n); also elsewhere on the board
/B.~RD~: U8.33 (Z80_RD_n); also elsewhere on the board
/B.~SH_DONE~: U8.49 (SH_DONE_n); also elsewhere on the board
/B.~SH_EN~: U8.47 (SH_EN_n); also elsewhere on the board
/B.~SH_INC~: U8.46 (SH_INC_n); also elsewhere on the board
/B.~SH_STB~: U8.45 (SH_STB_n); also elsewhere on the board
/B.~WR~: U8.35 (Z80_WR_n); also elsewhere on the board
/CPLD And Memory/ATL_A0: U8.53 (ATL_A0), U9.10 (A0)
/CPLD And Memory/ATL_A1: U8.54 (ATL_A1), U9.9 (A1)
/CPLD And Memory/ATL_A2: U8.55 (ATL_A2), U9.8 (A2)
/CPLD And Memory/ATL_A3: U8.56 (ATL_A3), U9.7 (A3)
/CPLD And Memory/ATL_A4: U8.57 (ATL_A4), U9.6 (A4)
/CPLD And Memory/ATL_D0: U8.58 (ATL_D0), U9.11 (I/O0), U10.21 (A11), U11.21 (A11), U12.25 (A11)
/CPLD And Memory/ATL_D1: U8.60 (ATL_D1), U9.12 (I/O1), U10.22 (A12), U11.22 (A12), U12.4 (A12)
/CPLD And Memory/ATL_D2: U8.61 (ATL_D2), U9.13 (I/O2), U10.23 (A13), U11.23 (A13), U12.28 (A13)
/CPLD And Memory/ATL_D3: U8.63 (ATL_D3), U9.15 (I/O3), U10.24 (A14), U11.24 (A14), U12.29 (A14)
/CPLD And Memory/ATL_D4: U8.64 (ATL_D4), U9.16 (I/O4), U10.32 (A15), U11.32 (A15), U12.3 (A15)
/CPLD And Memory/ATL_D5: U8.65 (ATL_D5), U9.17 (I/O5), U10.33 (A16), U11.33 (A16), U12.2 (A16)
/CPLD And Memory/ATL_D6: U8.67 (ATL_D6), U9.18 (I/O6), U10.34 (A17), U11.34 (A17), U12.30 (A17)
/CPLD And Memory/ATL_D7: U8.68 (ATL_D7), U9.19 (I/O7), U10.35 (A18), U11.35 (A18), U12.1 (A18)
/CPLD And Memory/L_A0: U8.72 (L_A0), U10.1 (A0), U11.1 (A0), U12.12 (A0)
/CPLD And Memory/L_A1: U8.75 (L_A1), U10.2 (A1), U11.2 (A1), U12.11 (A1)
/CPLD And Memory/L_A2: U8.76 (L_A2), U10.3 (A2), U11.3 (A2), U12.10 (A2)
/CPLD And Memory/L_A3: U8.77 (L_A3), U10.4 (A3), U11.4 (A3), U12.9 (A3)
/CPLD And Memory/L_A4: U8.78 (L_A4), U10.5 (A4), U11.5 (A4), U12.8 (A4)
/CPLD And Memory/L_A5: U8.79 (L_A5), U10.14 (A5), U11.14 (A5), U12.7 (A5)
/CPLD And Memory/L_A6: U8.80 (L_A6), U10.15 (A6), U11.15 (A6), U12.6 (A6)
/CPLD And Memory/L_A7: U8.81 (L_A7), U10.16 (A7), U11.16 (A7), U12.5 (A7)
/CPLD And Memory/L_A8: U8.83 (L_A8), U10.17 (A8), U11.17 (A8), U12.27 (A8)
/CPLD And Memory/L_A9: U8.84 (L_A9), U10.18 (A9), U11.18 (A9), U12.26 (A9)
/CPLD And Memory/L_A10: U8.85 (L_A10), U10.20 (A10), U11.20 (A10), U12.23 (A10)
/CPLD And Memory/TCLK: J2.1, U8.62 (TCK)
/CPLD And Memory/TDI: J2.9, U8.4 (TDI)
/CPLD And Memory/TDO: J2.3, U8.73 (TDO)
/CPLD And Memory/TMS: J2.5, U8.15 (TMS)
/CPLD And Memory/~ATL_CE~: U8.71 (ATL_CE_n), U9.20 (~CE)
/CPLD And Memory/~ATL_OE~: U8.70 (ATL_OE_n), U9.22 (~OE)
/CPLD And Memory/~ATL_WE~: U8.69 (ATL_WE_n), U9.27 (~WE)
/CPLD And Memory/~CE0~: D4.1 (K), U8.90 (RAM_CE0_n), U10.6 (~CE)
/CPLD And Memory/~CE1~: D5.1 (K), U8.92 (RAM_CE1_n), U11.6 (~CE)
/CPLD And Memory/~CE2~: D3.1 (K), U8.98 (ROM_C2), U12.22 (CE)
/CPLD And Memory/~OE~: U8.93 (RAM_OE_n), U10.31 (~OE), U11.31 (~OE), U12.24 (OE)
/CPLD And Memory/~WE~: U8.94 (RAM_WE_n), U10.13 (~WE), U11.13 (~WE)
/D_DIR: U8.22 (L_DIR); also elsewhere on the board
/MCLK: U8.87 (MCLK); also elsewhere on the board
/SH_C_DIR: U8.44 (SH_C_DIR); also elsewhere on the board
/~BOOT_EN~: U8.88 (BOOT_EN_n); also elsewhere on the board
/~INT~: U8.96 (Z80_INT_n); also elsewhere on the board
/~RESET~: U8.89 (RESET_n); also elsewhere on the board
/~SH_BUSY~: U8.50 (SH_BUSY_n); also elsewhere on the board
/~SH_D_OE~: U8.52 (SH_D_OE_n); also elsewhere on the board
/~WAIT~: U8.97 (Z80_WAIT_n); also elsewhere on the board
/~Z80_D_OE~: U8.23 (Z80_DATA_OE_n); also elsewhere on the board
GND: C10.2, C11.2, C12.2, C13.2, C14.2, C15.2, C16.2, C17.2, C18.2, C19.2, C20.2, C21.2, C22.2, C23.2, C24.2, C25.2, J2.2, J2.10, U8.11 (GND), U8.26 (GND), U8.38 (GND), U8.43 (GND), U8.59 (GND), U8.74 (GND), U8.86 (GND), U8.95 (GND), U9.1 (A14), U9.2 (A12), U9.3 (A7), U9.4 (A6), U9.5 (A5), U9.14 (GND), U9.21 (A10), U9.23 (A11), U9.24 (A9), U9.25 (A8), U9.26 (A13), U10.10 (GND), U10.28 (GND), U11.10 (GND), U11.28 (GND), U12.16 (GND); also elsewhere on the board
unnamed: D1.2 (A), R1.2
unnamed: D1.1 (K), U8.100 (IO100)
unnamed: D2.2 (A), R2.2
unnamed: D2.1 (K), U8.99 (IO99)
unnamed: D3.2 (A), R3.1
unnamed: D4.2 (A), R4.1
unnamed: D5.2 (A), R5.1

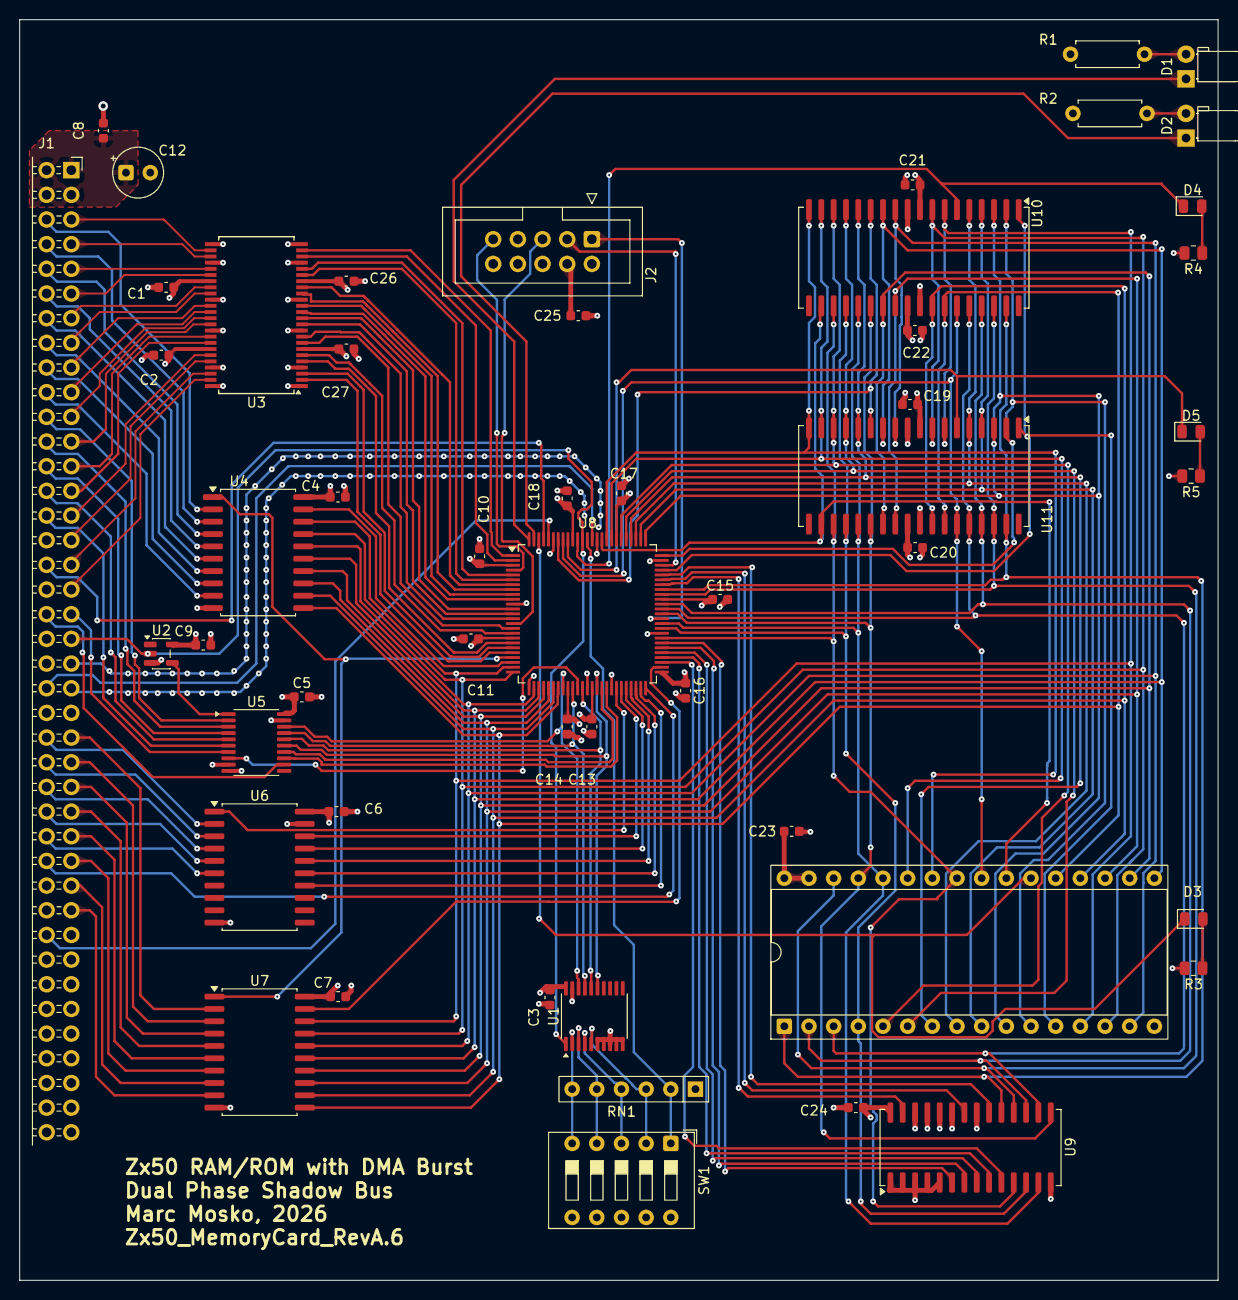
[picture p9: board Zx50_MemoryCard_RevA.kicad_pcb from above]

Board: 4 copper layers, 123.4 x 129.8 mm, 53 parts (0 on the bottom side), 140 nets.

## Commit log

2026-03-11 RevA.6 as sent to fab.
    [Zx50_MemoryCard_RevA.kicad_pcb, Zx50_MemoryCard_RevA.kicad_sch]
2026-03-13 move files in big reorg
    [Zx50_MemoryCard_RevA.kicad_pcb, Zx50_MemoryCard_RevA.kicad_sch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]
2026-03-13 unify kicad for zx50 in one repo
    [Z80home_RevC.kicad_pcb, Z80home_RevC.kicad_sch, Zx50 Bus Probe_RevA.kicad_sch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]
2026-03-14 before routing
    [Zx50_Cpu.kicad_pcb, Zx50_Cpu.kicad_sch]
2026-03-14 add csv files.
    [2026-03-07 19_18 From Parts Cart JLCPCB Parts.csv, 2026-03-07 20_19 From Parts Cart JLCPCB Parts.csv, Z80home_RevC.csv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]
2026-03-14 add mounting holes
    [Zx50_Clock_Mezzanine_RevA.kicad_pcb, Zx50_Cpu.kicad_pcb, Zx50_Cpu.kicad_sch]
2026-03-15 finish up cpu card, begin on serial card.
    [Zx50_Cpu.csv, Zx50_Cpu.kicad_pcb, Zx50_Cpu.kicad_sch]
